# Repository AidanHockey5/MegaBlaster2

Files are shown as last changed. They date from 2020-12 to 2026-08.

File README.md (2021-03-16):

# Mega Blaster 2

Demo video can be found here: https://www.youtube.com/watch?v=4sKwGWfikdc

[Instruction Manual](https://github.com/AidanHockey5/MegaBlaster2/raw/master/man/MegaBlaster2InstructionManual.pdf)

[Store Link](https://www.aidanlawrence.com/product/mega-blaster-2/)

[Discord Link](https://discord.gg/M2skqkZhw2)

This project contains the source material for the Mega Blaster 2, a hardware Sega Genesis/Mega Drive video game music (VGM) player that utilizes the real sound chips. Play any Genesis track on-demand with brilliant sound quality on the actual YM2612/YM3438 and SN76489 PSG synthesizer chips that were found in the real Genesis consoles(1). The Mega Blaster 2 is compatible with both .vgm and .vgz files and can support both the YM2612 and YM3438 simply by changing the DIP switch values. This unit does not use any emulated sound - these are the real chips playing back logged data from the vgm files. 

# VGM Files

VGM files are logged datasets of the data that would have been sent to the real sound chips of whatever console or arcade machine was being sampled. The Mega Blaster 2 simply reads-in this data and sends it to the sound chips at the exact rate specified in the VGM spec, accurately recreating the original sound.

You can find Genesis VGM files here: https://project2612.org/list.php

You can find more VGM files here: https://vgmrips.net/packs/

Please make sure to remove any non-vgm/vgz files before adding them to your Mega Blaster 2's SD card, such as album art images, playlist files, and text files.

# VGM vs. VGZ

VGZ files are gzip compressed versions of VGM files. The Mega Blaster 2 is capable of automatically decompressing these vgz files on-the-fly at a slight performance penalty. If you'd like faster load times for each track, consider decompressing the VGZ files in advance by opening them with a program like [7zip](https://www.7-zip.org/)
The Mega Blaster 2 does not require file extensions in order to operate as it will verify files based on their internal headers.

# Building Your Own Unit

Here are some quick tips for building your own board.

1) You can find an interactive Bill of Materials (BOM) within the `schematic->bom` folder. Open the HTML file in any browser for an easy-to-use part position guide.
2) I use [KiCAD](https://kicad.org/) as my EDA suite.
4) I buy most of my components from [LCSC](https://lcsc.com/). I buy my PCBs from [JLCPCB](https://jlcpcb.com/). If you buy your PCBs from JLCPCB, you can often get a shipping discount on your LCSC parts order.
5) You will need an [Atmel ICE](https://www.microchip.com/DevelopmentTools/ProductDetails/ATATMEL-ICE) or [Jlink](https://www.segger.com/products/debug-probes/j-link/) to flash the bootloader. Once you have flashed the bootloader, all subsequent programming can be done via the on-board USB port. A cheaper option would be to grab a [Jlink EDU Mini](https://shop-us.segger.com/J_Link_EDU_mini_p/8.08.91.htm) as they feature the full functionality of a professional Jlink Unit with the stipulation that it is ONLY to be used for educational purposes. I personally use an Atmel ICE unit. You can find the bootloader bin file in the `bootloader` folder of the repository. [You can find an example of me programming the bootloader using Microchip Studio here.](https://youtu.be/FjPftGuLnGg?t=9259)
6) Once you've flashed the bootloader, you can drag the [.uf2 firmware file found on the releases page](https://github.com/AidanHockey5/MegaBlaster2/releases) on to the "drive" that pops up on your computer, or build from source. If you can't see any "drive," make sure the bootloader mentioned above is flashed correctly, then try double-tapping the RESET button. 
7) If your OS reports a USB fault, you may have a short somewhere on your USB IO lines, power lines, or your 32.768KHz crystal is not hooked up correctly.
8) I use [Visual Studio Code](https://code.visualstudio.com/) with the [PlatformIO](https://platformio.org/install/ide?install=vscode) extension.
9) Make sure your SN76489 PSG chip is orientated correctly. On this board, the PSG is upside-down relative to the rest of the board. The Flash IC is also upside-down. This was done for routing purposes. A small star on the silk-screen indicates the pin-1 position of every IC.
10) For general usage instructions, [please refer to the manual](https://github.com/AidanHockey5/MegaBlaster2/raw/master/man/MegaBlaster2InstructionManual.pdf).

# Reporting Bugs

As you can imagine, this is quite a complex project. There are bound to be bugs to squish, so if you happen to find any, [please report them over on the issues page](https://github.com/AidanHockey5/MegaBlaster2/issues) so I can tkae a look at them! Please try to document the steps it takes to recreate the bug if you happen to know them.

# Schematic

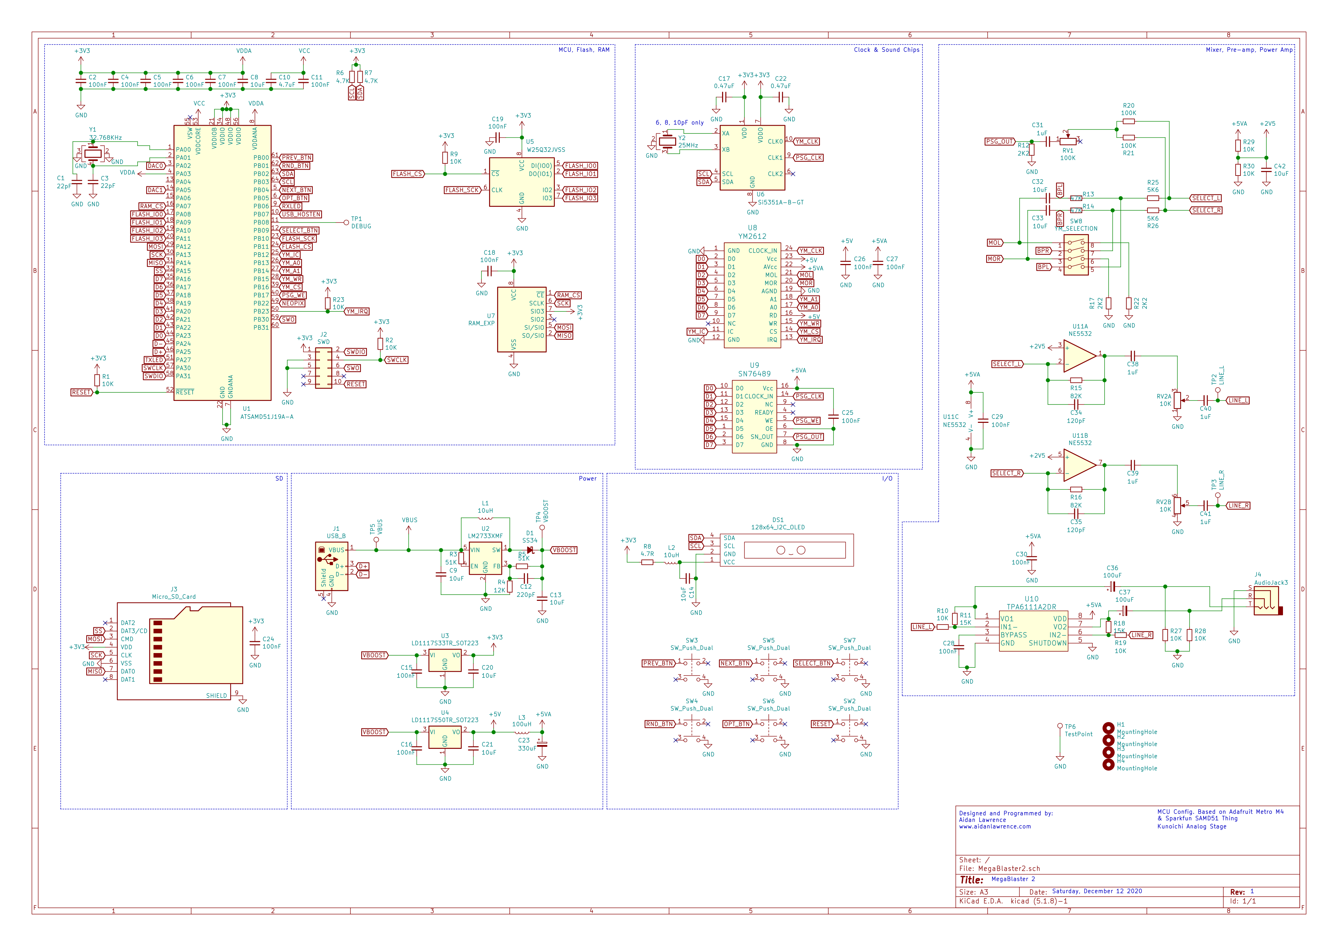
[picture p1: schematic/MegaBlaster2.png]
Schematic


# License
The source code to this project is licensed under the AGPL 3.0 license.

The printed circuit board design files for the Mega Blaster 2, including it’s schematic, gerber files, KiCAD files, bill-of-materials, and 3D models are licensed under the Creative Commons Attribution-NonCommercial-ShareAlike 4.0 license.

You are permitted to build your own Mega Blaster 2 units for personal use. You are not permitted to sell said units.

(1) Pedantic note: Discrete YM2612 ICs were indeed included on some models of the Genesis, but the SN76489 PSG and YM3438 were found baked into ASIC chips on the actual consoles. The PSG's noise is slightly different on the ASIC version.

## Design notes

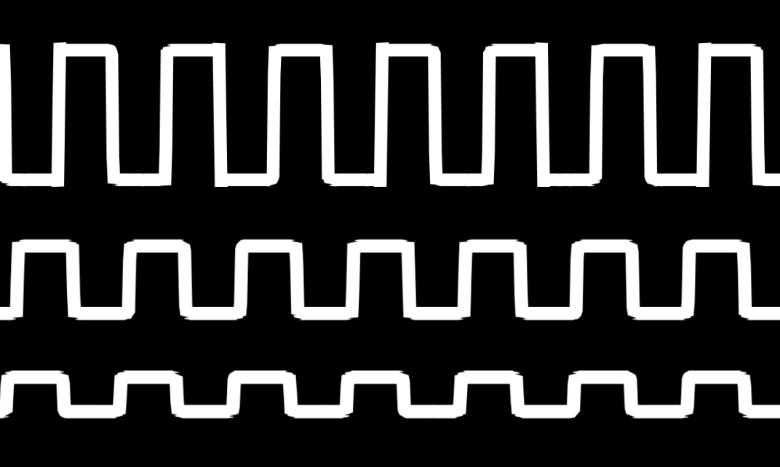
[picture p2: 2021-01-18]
schematic/Art/Square_half.bmp

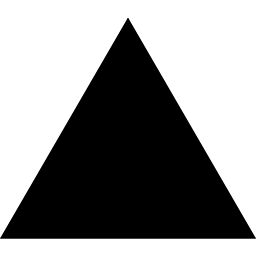
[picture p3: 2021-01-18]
schematic/Art/Triangle.bmp

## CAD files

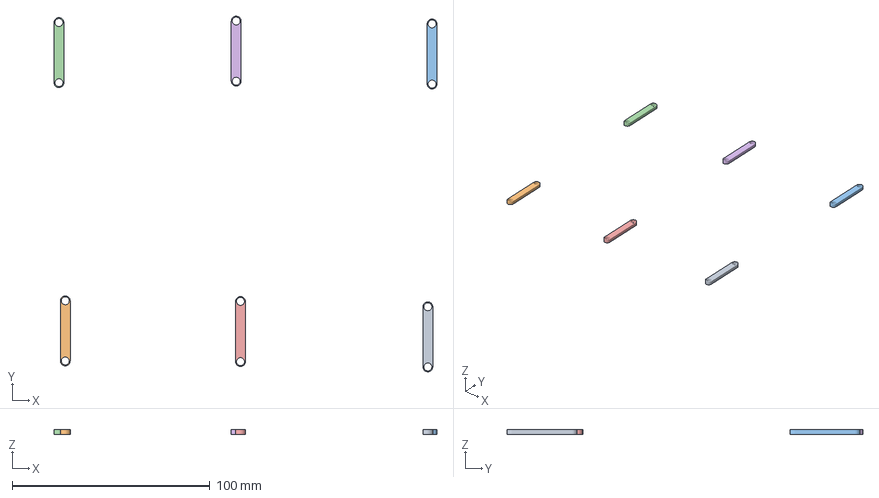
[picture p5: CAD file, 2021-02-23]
3D_Print/6x_OLED_Spacer_1.3mf
193.7 x 179.9 x 2.50 mm
OLED_Spacer_1.stl x 6

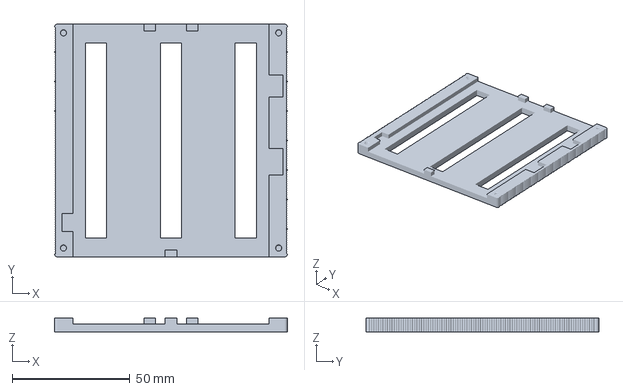
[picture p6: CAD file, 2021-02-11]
3D_Print/MegaBlaster2_Baseplate_V3.3mf
99.0 x 99.0 x 6.00 mm

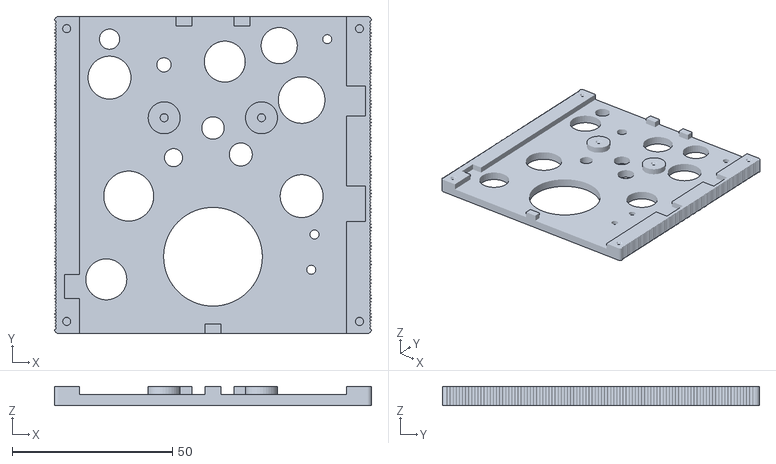
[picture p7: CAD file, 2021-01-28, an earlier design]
3D_Print/MegaBlaster2_Baseplate_V1.stl
99.0 x 99.0 x 6.00

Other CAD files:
3D_Print/MegaBlaster2_Baseplate_V2.3mf
3D_Print/MegaBlaster2_Baseplate_V2.stl
3D_Print/MegaBlaster2_Baseplate_V3.stl

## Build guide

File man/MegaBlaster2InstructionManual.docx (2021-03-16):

MEGA

BLASTER

2

Sega Genesis / Mega Drive Video Game Music Player

User Manual

Aidan Lawrence

www.aidanlawrence.com

March 2021

# Quick Start

The Mega Blaster 2 is designed to play both uncompressed (.vgm) and compressed (.vgz) Video Game Music (VGM) files. The device will read-in VGM files from the SD card, parse them, and send the data inside of those files to the sound chips, accurately recreating the music using authentic hardware.

In order to use the Mega Blaster 2, you must have:

- A microSD card formatted to FAT32 (plus an SD card reader for your PC).
- A standard USB-B cable and a USB port (for power. Standard USB phone chargers also work).
- 3.5mm audio cable for external speakers/line devices OR headphones with a 3.5mm jack.
- (Optional USB support) Windows 7 and 8 users will need a driver, which you can download here. (https://github.com/adafruit/Adafruit_Windows_Drivers/releases/download/2.3.4/adafruit_drivers_2.3.4.0.exe)

Format the SD card to FAT32. Load the SD card with VGM files on your PC. Be sure to remove any non-VGM files (album art images, txt files, m3u files, etc. should not be placed on the SD card). Eject the card and insert it into the Mega Blaster 2. Plug-in the Mega Blaster 2 via USB to power-on. After the power-on-self-test and boot screen, your device should be ready to go!

If you have any questions about the operation of the Mega Blaster 2, feel free to send me an email. You can reach me via my Contact page on my website:

https://www.aidanlawrence.com/contact/

or visit the Discord server: https://discord.gg/5rDChhUexQ

# Device Guide

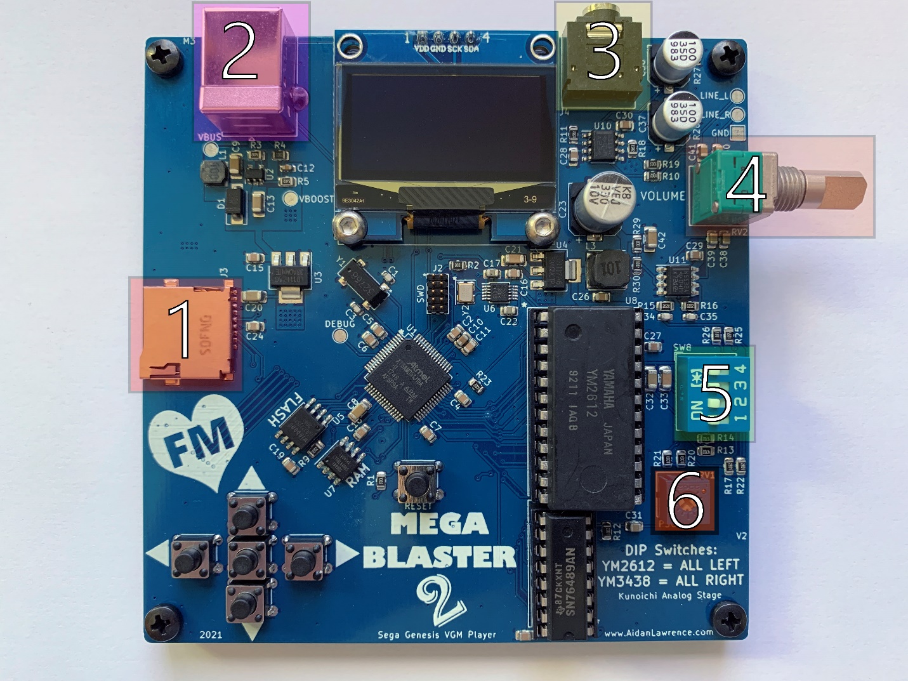
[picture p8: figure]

1) Micro SD Card Socket: Push your SD card in until you hear a click. Push the card again to eject.
2) USB Connector: Power your device using a USB-B cable. Any USB port should be able to supply enough power to the Mega Blaster 2, including PC USB ports and 5V cellphone chargers.
3) Audio Out Jack: TRS amplified audio out. The Mega Blaster 2 features a small headphone amplifier, so directly driving phones is OK. Line level outputs are broken out on the upper right-side of the board, though, it’s probably much easier to simply lower the volume for driving line-level input devices if clipping is occurring.
4) Volume Knob: A simple volume potentiometer. Clockwise turns increase the volume, counterclockwise turns decrease the volume.
5) YM2612/YM3438 Selection DIP Switches: YM2612’s and YM3438’s have different output impedances. Use these DIP switches to select the correct mixing resistors.
  a. For YM2612: Set all DIP switches to the LEFT side.
  b. For YM3438: Set all DIP switches to the RIGHT side.
6) PSG (SN76489) Mix Volume: This potentiometer adjusts the PSG square wave volume. You can use a screwdriver to turn this potentiometer. Clockwise for a quieter PSG, counterclockwise for a louder PSG.

# SD Card Setup

You must format your SD card as a FAT32 device. You can simply use your built-in operating system’s tools to format your card or use the official formatting tool from the SD Association. (https://www.sdcard.org/downloads/formatter/)

Folders/directories are supported on the Mega Blaster 2. However, due to memory restrictions, the device will only read one level deep into a directory structure. Basically, that means you can have folders, but you cannot have folders-within-folders. Files placed on the root directory of the SD card are also OK.

Please only include .vgm and .vgz files for best performance (.vgz files may take slightly longer to start playing due to decompression). Make sure to delete any non-VGM files.

If your SD card fails to read, the display will warn you on start-up.

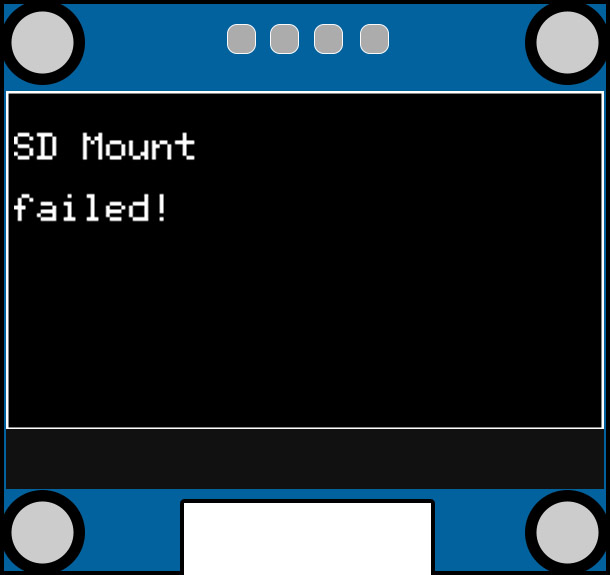
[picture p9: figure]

Check that your card is formatted to FAT32 and is not physically damaged. If you happened to have interrupted the card via a reset, programming cycle, or the player has crashed; remove the card, reinsert the card, and then press the RESET button.

On Windows, drives larger than 32GB will lose their option to be formatted as FAT32 devices in the default Windows formatting tool. You can use a tool like FAT32 Format GUI (http://ridgecrop.co.uk/index.htm?guiformat.htm) to get around this limitation.

# Chip Verification

The Mega Blaster 2 will automatically verify your YM2612/YM3438 chip on every startup by setting the internal timers and listening for specific interrupt intervals from the IRQ pin. If the Mega Blaster does not detect these specific pulses from the IRQ pin within one second after startup, the player will lock up and flash a warning on the screen prompting you to power the device down and remove the offending sound chip. This procedure is to combat the growing number of fraudulent chips being passed as YM2612/YM3438’s and to warn the user before any possible damage occurs from using a counterfeit chip.

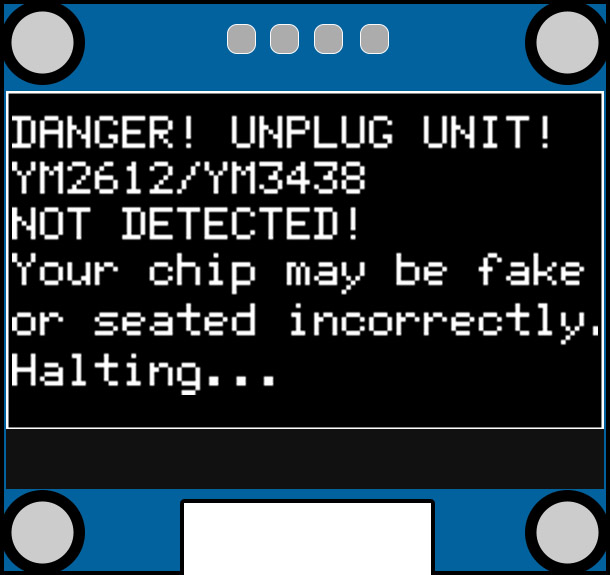
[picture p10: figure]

If you see the above message after you power up your device, immediately remove power and remove the YM2612/YM3438. Your chip has likely been detected as a fake. You may also see this message if your chip isn’t seated correctly or there is a hardware fault such as a short circuit or a damaged component.

Regardless of the issue, if you see this screen, then something isn’t right!

# Video Game Music (VGM) Files

Video Game Music files, referred to as “VGM files,” are essentially log files of the data that was sent to the sound hardware on the real versions of their target consoles/arcade machines. The Mega Blaster will interpret these data logs and send commands to the sound chips at nearly the same time as the real hardware would have sent data over to its sound chips. The result is a near 1:1 recreation¹ of the original sound on-demand that’s fed through modern amplification circuitry to produce a crystal-clear output. There is absolutely no emulation here – everything is being synthesized on-the-fly using the genuine sound chips.

You can download Genesis/Mega Drive VGM files here: https://project2612.org/list.php

The Mega Blaster 2 also supports any VGM file that leverages the SN76489 PSG, such as Sega Master System VGMs.

Additional VGMs can be found here: https://vgmrips.net/packs/

Please note that Sega CD and 32X VGMs are not supported as they used separate sound hardware. 3rd party tracks that utilize DAC streams are supported, however. VGMs that use chips other than the YM2612/YM3438 and SN76489 PSG are not supported.

# VGZ vs VGM

VGZ files are compressed VGM files. The Mega Blaster 2 supports both compressed and uncompressed VGM files natively. However, it’s a better idea to use decompressed VGM files on your Mega Blaster 2 as it will drastically increase your performance as no decompress cycle needs to happen before each track.

You can use a tool like 7zip (https://www.7-zip.org/download.html) to easily extract the VGM files out of VGZ files.

File extensions, or lack thereof, do not matter.

¹Time resolution on microcontroller timers isn’t infinite, so there will be an ever-so-slight variation in timing compared to the real hardware (~0.1% inaccuracy). This really isn’t perceptible to humans though, so it’s pretty much a non-issue, but is worth mentioning for the sake of disclosure.

# The Main Menu

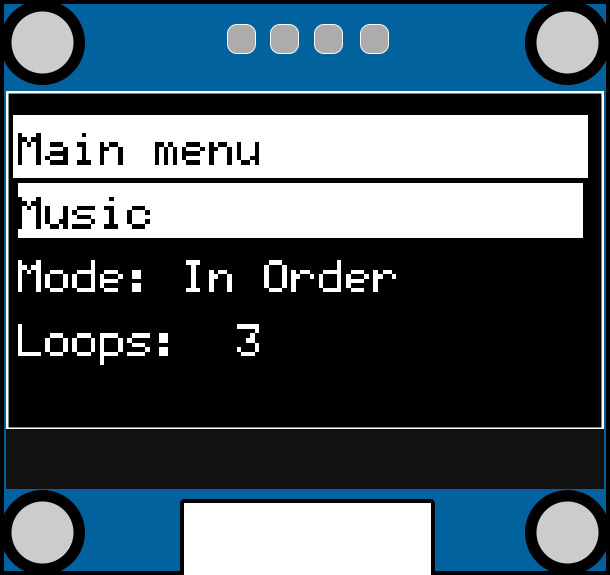
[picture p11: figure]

Once your Mega Blaster 2 boots, you will be placed onto the main menu screen. Here, you can access your music browser and change settings.

You can use the directional buttons on the bottom left of the Mega Blaster 2 to move around this menu. The middle “select” button (and the right arrow button) can be used to enter menus and options.

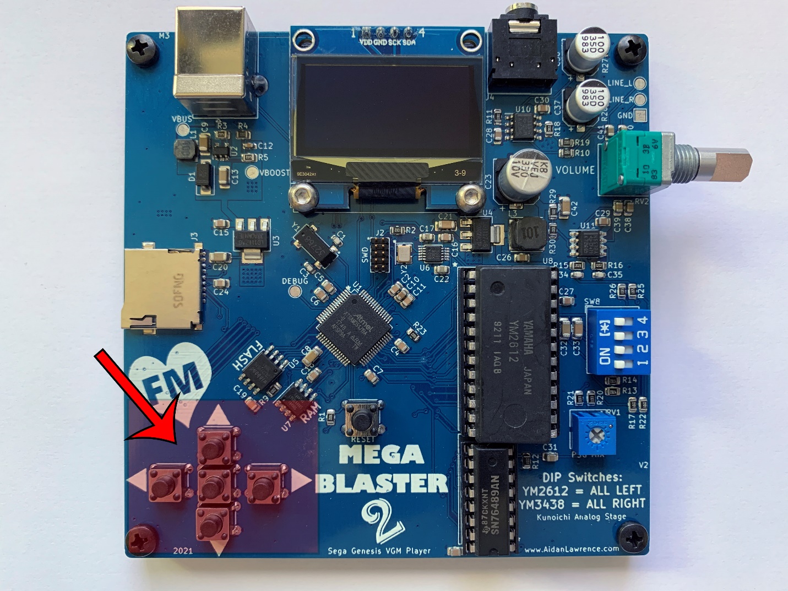
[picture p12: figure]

# File Browser (Music Menu)

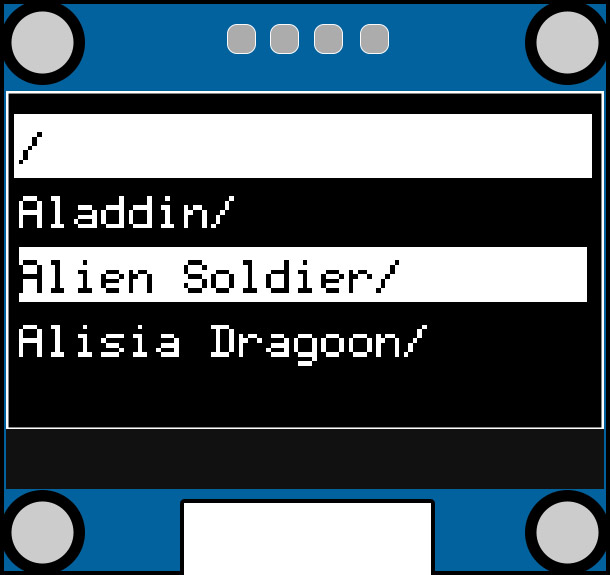
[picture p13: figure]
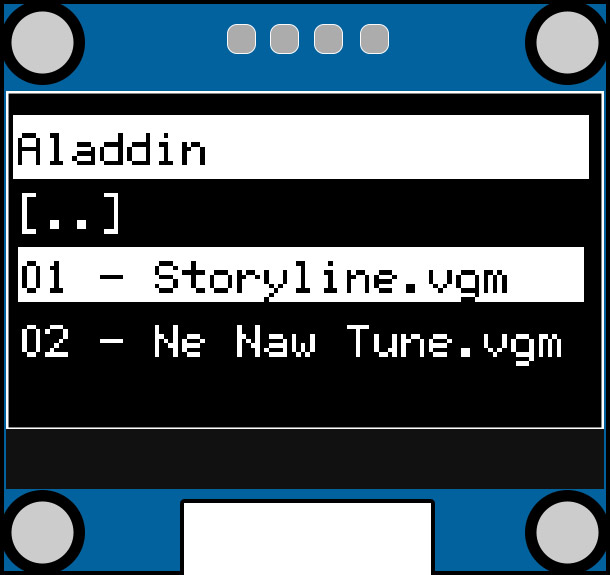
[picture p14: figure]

To access your video game music tracks, you will need to interface with the file browser found under the “Music” main menu option.

Simply use the up and down keys to scroll through your folders and files. You can enter directories and select files using the middle select button or the right arrow button. You can leave a directory by using the left arrow button, or by selecting the [..] entry.

Once a valid VGM or VGZ file is selected, the player will automatically verify it and begin playing. You will be taken to the Track Information screen.

Note: the _SYS directory is created by the Mega Blaster 2 itself and should simply be ignored. This directory is where the decompressed VGM data is stored.

Files are read in-order directly from the SD card. They are not sorted in alphabetical order. If you’d like your SD card to be sorted in alphabetical order, you will need a tool that sorts your files in advance.

SD Sorter (https://www.trustfm.net/software/utilities/SDSorter.php) does this admirably.

# Track Information Screen

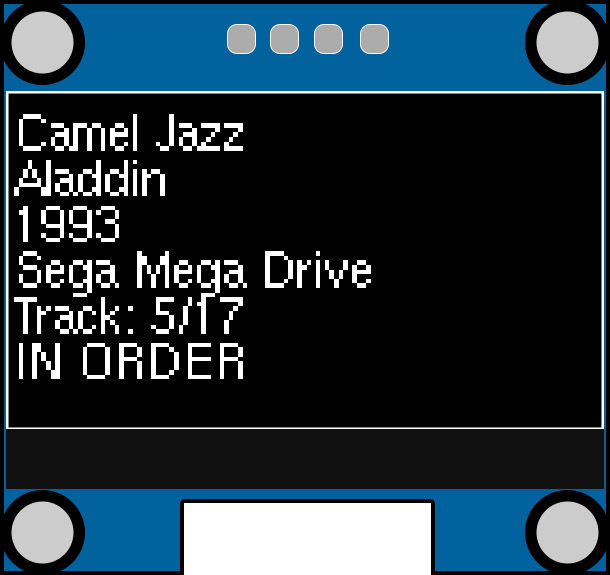
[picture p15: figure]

While the device is playing a track, the information screen will appear. Here, you will see the following information:

Track name

Game Name

Date of Game Release

Game System

Track #/# of total tracks in directory

Play Mode (IN ORDER/LOOP/SHUFFLE DIR/SHUFFLE ALL)

You can exit this screen at any time and return to the menu system by pressing the middle select button.

If you idle in the menu system, the Mega Blaster 2 will automatically return to this screen.

If you are in the “Shuffle Dir” or “Shuffle All” play mode, the current track number is not shown.

# Info Screen Controls

While in the information screen, your controls will automatically change to playback controls.

The up and down keys are disabled.

The middle select button will return you to the menu system.

The left and right buttons will move you forwards or backwards through the tracks depending on your current play mode.

If you are set to the “In Order” or “Loop” play mode, your left and right buttons will cycle through the files in your current directory in order.

If you are set to the “Shuffle All” or “Shuffle Dir” play mode, your left and right buttons can be used to travel in-order through the random shuffle history. Once you’ve reached the near-end of the random shuffle history using the left arrow button, you won’t be allowed to go back any further. Once you’ve reached the far-end of the shuffle history using the right arrow button, a new track will be randomly selected and stored in the shuffle history in case you’d like to go back to it at any point.

# Play Modes

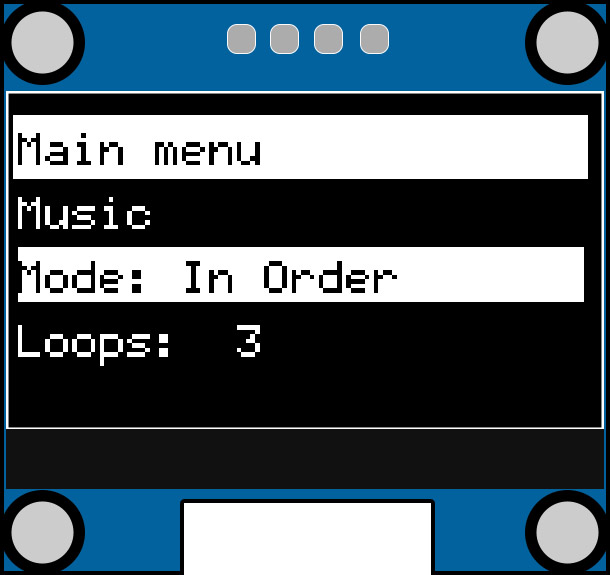
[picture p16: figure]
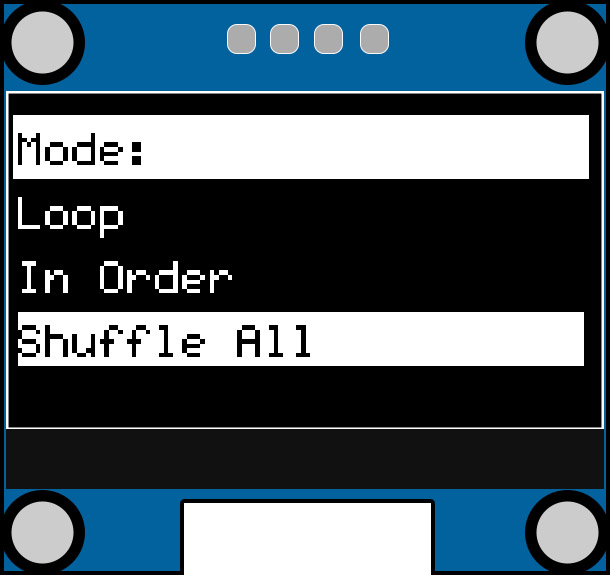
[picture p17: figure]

The Play Mode menu allows you to select the player’s automatic track swapping behavior.

There are 4 possible play modes to choose from:

Loop: Re-play the current track perpetually until manually changed by the user.

In Order: Once a track is chosen, the player will automatically proceed to the next track file in the current directory after the previous track ends.

Shuffle All: This option will automatically start playing the entire SD card in a random order. Every single VGM track on-board is eligible to be selected at random after each track ends.

Shuffle Dir: Similar to the “Shuffle All” function, but the pool of tracks to pick from is confined to a single directory.

The default value is “In Order.”

# Adjust Number of Loops

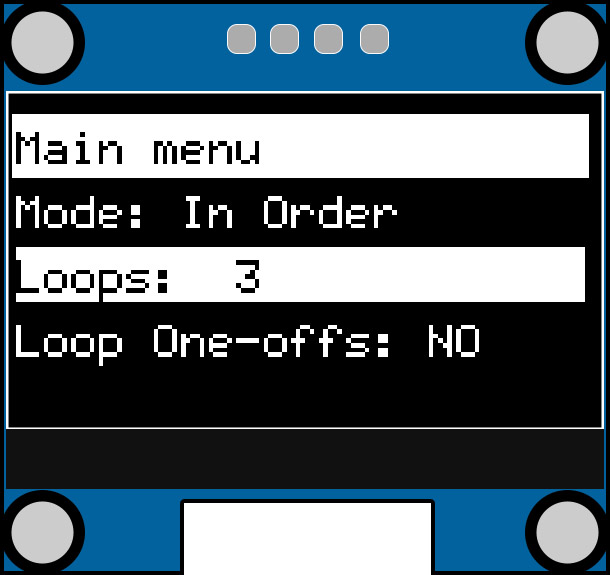
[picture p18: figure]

The “Loops” option will allow you to change the number of times a track will loop before ending. To change the loops value, highlight it with your cursor and hit the middle select button.

For fine control, hit the select button once. A colon character ( : ) will appear next to the value. Use the up and down buttons to adjust the loops by 1.

For coarse control, hit the select button once again. An angle bracket character ( > ) will appear next to the value. Use the up and down buttons to adjust the loops by 10.

Finally, hit the selection button once more to exit.

The default value is “3.”

Note: If your play mode is set to “Loop,” this value will be set to 65535 (Internally, the Mega Blaster 2 reads this as 0xFFFF, indicating that a track should be looped forever).

# Loop One-offs

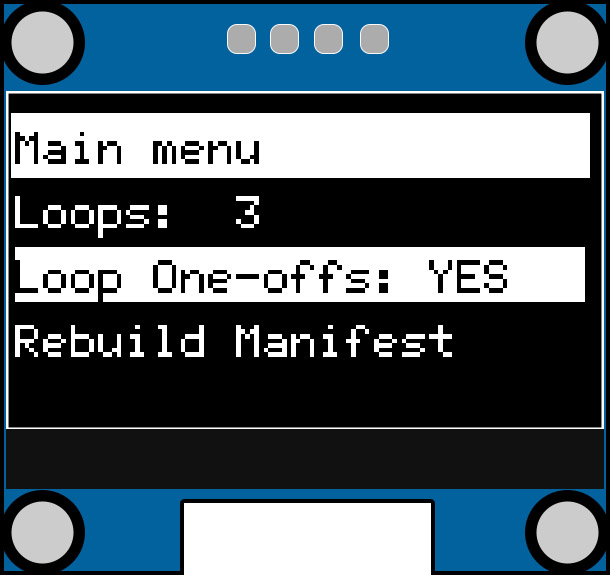
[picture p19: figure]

This option will give you the ability to change if one-off tracks will loop just like any other track. Usually, one-off tracks are things like game-over themes, intro themes, or other minor jingles.

You can adjust this setting by highlighting the option, hitting the middle select button, then using the up and down buttons to change the value. Once you’ve selected your value, hit the middle select button again to set.

This option defaults to “NO.”

# Audio Performance Considerations

The Mega Blaster 2 uses custom power filtering circuitry and careful PCB routing to ensure the best possible signal-to-noise ratio. Any device with a USB port should be able to power the Mega Blaster 2 just fine, but there are still a few considerations to make depending on your configuration.

# Ground Loops

If you power your Mega Blaster 2 via your computer’s USB port and connect the audio output to the same computer’s line-in, you will form a ground loop and will likely hear a loud buzzing noise or amplified electromagnetic interference. You can easily solve this issue with a cheap ground loop isolator. They look like this:

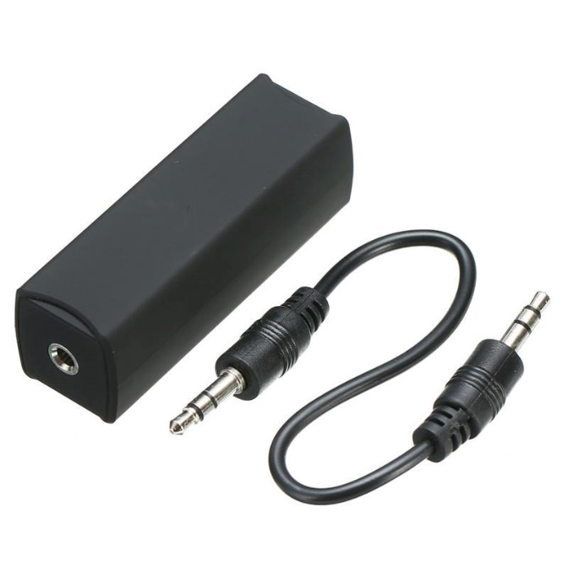
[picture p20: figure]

Keep in mind that many ground loop isolators are designed with a low-pass filter built-in and this can affect audio quality. Users with headphones directly connected to the Mega Blaster 2 will not have to worry about such ground loops.

Alternatively, you can use an external power source like a 5V portable battery bank to power the Mega Blaster 2. This will eliminate the need for a ground loop isolator.

On the topic of headphones: The Mega Blaster 2 does feature a small headphone amplifier on its output. The onboard headphone amplifier is the TPA6111A2 and is capable of delivering up to 150mW of power directly to headphones. The TPA6111A2 is a linear class AB amplifier. You can read more about its specifications in the TI datasheet. (https://www.ti.com/lit/ds/symlink/tpa6111a2.pdf?ts=1612621494673)

Finally, it’s important to distinguish the noise floor differences between the YM2612 and the YM3438. The YM2612 has a higher noise floor than the YM3438. YM2612 users may be able to hear a very slight white-noise hiss when the unit is not playing any music. This is totally normal and is an artifact of the time-division multiplexor cycling through each of the FM channels. There is no way around this noise floor as it is literally the YM2612 itself producing it. It’s one of the quirks of using real hardware instead of an emulator! The YM3438 has a noticeably lower noise floor.

# Firmware Updates

The Mega Blaster 2 features an easy-to-use UF2 bootloader which makes updating the onboard firmware as easy as dragging a file to a flash drive.

## Windows, MacOS, and Linux

If you’re using a Windows 10, MacOS, or Linux computer, your driver should install automatically. Otherwise, Windows 7 and 8 users should install the Adafruit drivers found here. (https://github.com/adafruit/Adafruit_Windows_Drivers/releases/download/2.3.4/adafruit_drivers_2.3.4.0.exe)

Updating your firmware is as simple:

1) Download the latest .uf2 firmware file from the GitHub Repository Releases (https://github.com/AidanHockey5/MegaBlaster2/releases/) page.
2) Double-tap the RESET button on your Mega Blaster 2. A new “drive” named “MB2BOOT” should pop up and/or be available in your “This Computer” or drive browser.
3) Drag the UF2 firmware file on to this “drive” just like a flash drive. Once the Mega Blaster 2 verifies the file, it will automatically flash itself and reboot.
4) You may need to remove and reinsert your SD card, then hit the RESET button a single time.

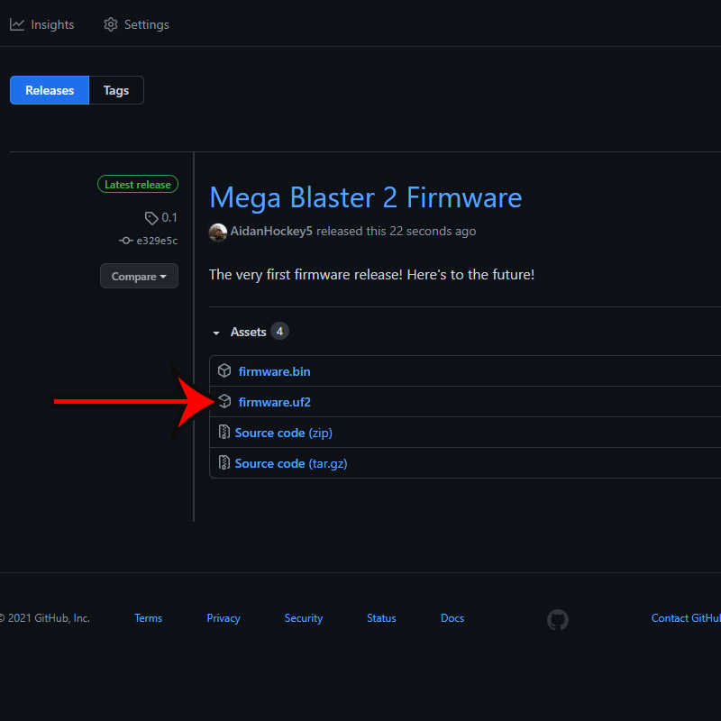
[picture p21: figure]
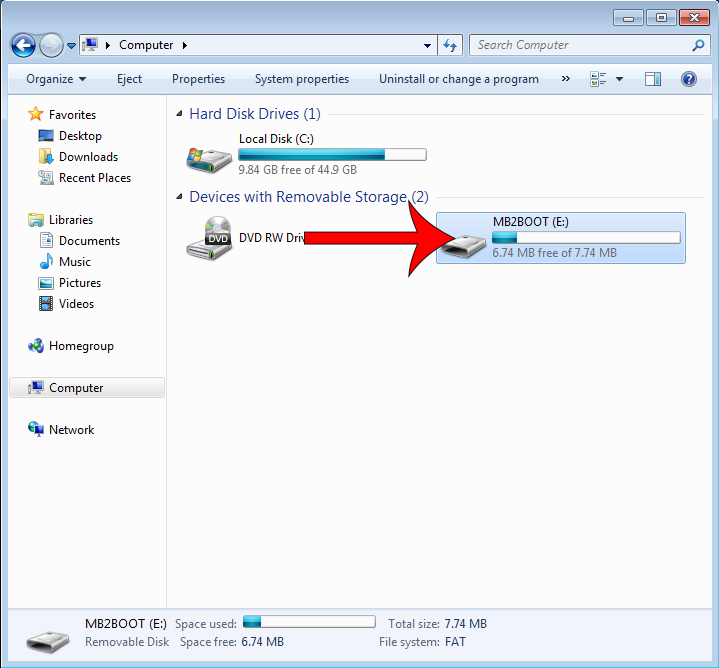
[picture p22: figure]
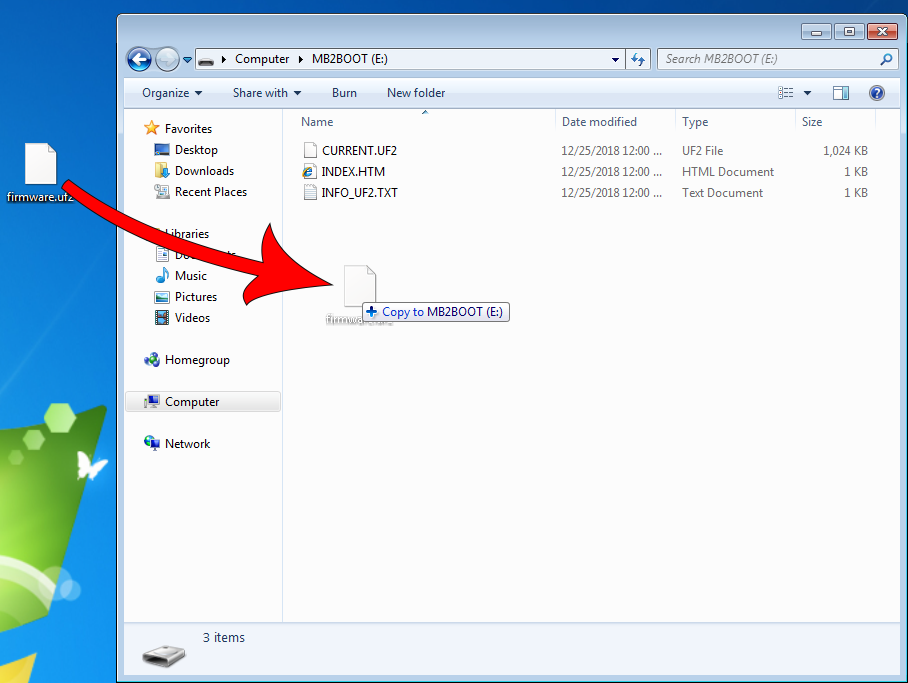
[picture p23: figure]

The process is the same for MacOS and Linux (lubuntu shown here).

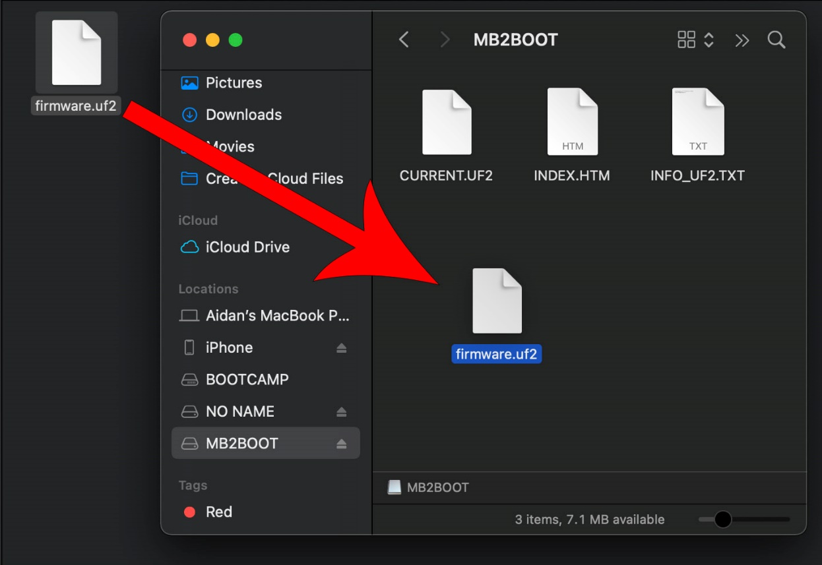
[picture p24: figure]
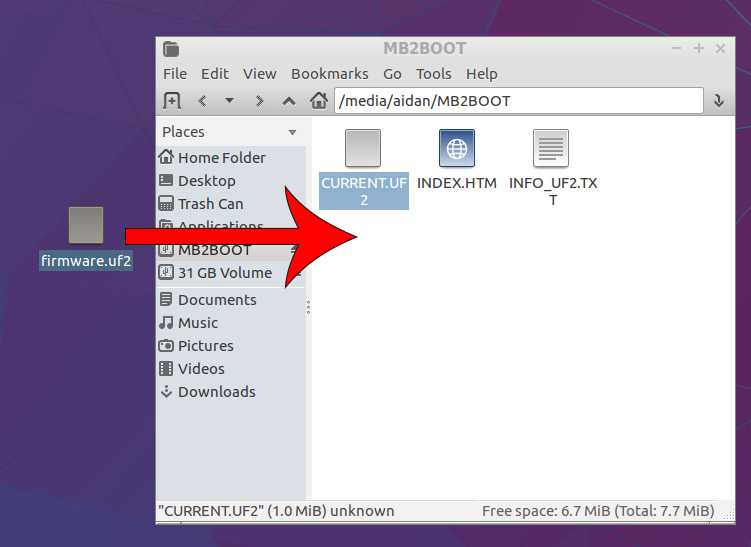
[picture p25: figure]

# Getting Help

Stuck updating? Have any questions or comments? Just want to chat about sound chips?

Feel free to join the Discord server! https://discord.gg/5rDChhUexQ

…or contact me via email here: https://www.aidanlawrence.com/contact

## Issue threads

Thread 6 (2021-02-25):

Directories that begin with the same string are indexed incorrectly

AidanHockey5, 2021-02-25:
A new issue has been found where if two directories begin with the same string, the player indexes them incorrectly.

For example, if you had two directories from the same franchise, they might have folders like this:

```
Shining Force
Shining Force II
```

The player will then index both of these folders together, giving incorrect values on how many tracks are actually in a specific folder. Eventually the player will jump out of those bounds and end up in an invalid state.

The probable cause of this issue is due to how the Arduino Menu library indexes directories using a `startsWith()` function, or something along those lines. Fixing this issue might take a little while due to the inherent complexity of the library, but I am aware of it.

A work-around right now would be to start similar directories with numbers preceding them, like so:

```
1_Shining_Force
2_Shining_Force
```

birdybro, 2021-02-28:
Also probably related to the same thing...

[MANIFEST.txt](https://github.com/AidanHockey5/MegaBlaster2/files/6058037/MANIFEST.txt) <--- my manifest.

Added some to the manifest to test, it got reallly crazy from here. Everything in a strange order now, looks the same upon forcing a manifest rebuild. Also randomly now a bunch of tracks just skip around.

Just noticed the freefilesync db file, removing that file to see if it clears up the issue. At first I was thinking that some arcade system tracks with compatible chips were just not playing for whatever reason. Saw a strange one where columns 2 arcade was just rapidly changing tracks and I couldn't stop it, had to pull the plug. Interesting.

Deleting the ffs sync db file didn't fix the issue. Upon initial boot columns 2 does the same loop through tracks infinitely. If I play some other stuff, then it works occasionally. Kinda strange.

AidanHockey5, 2021-02-28:
Hrm.. interesting. A friend of mine reported an issue with their manifest file too similar to yours. The text portion of the manifest file looks like it generated successfully, but the metadata bytes concatenated to the end look duplicated.
Try deleting the _SYS folder on your machine and letting the player generate a brand new manifest from scratch.

I'm actually going to be out of office for the next week, so I'll be on bug patrol the following week. Ditching this manifest system is something that I'd like to do in the future, but that's a pretty big fix, so it might take a bit of time. Hopefully the new system will patch out the original issue above too.

birdybro, 2021-03-08:
Just as an update for the purposes of providing more data if you need it, when I redid the manifest entirely, this is the result:

[MANIFEST.zip](https://github.com/AidanHockey5/MegaBlaster2/files/6104599/MANIFEST.zip)

Still gets out of order by the end of it.

When I wipe the manifest and start over, same result. So at least it's reproducible! :)

AidanHockey5, 2021-03-09:
Yeah, I’m on my way back from a trip and am thinking of a way to remove the
manifest system entirely. I’m not entirely sure what your unit is doing. I
wonder if a track file name happens to have a weird character in it or
something is overflowing.

I’ll certainly take a look at this when I get home and see what I can do.

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

AidanHockey5, 2021-03-12:
Just a progress report on this issue:
I've been working on a new way to ditch the manifest system at the expense of a little more memory usage. I've got a version that seems to be working pretty well right now as of [this commit](https://github.com/AidanHockey5/MegaBlaster2/commit/1779ea2c6d107876efd6414b146e4b1de1a98458)

Much more testing will be required before it's all done, but early signs look good. I'd also like to create a system to delete or avoid garbage OS files and directories like .DS_Store etc. Those files tend to not do anything terribly important and really only seem to exist to gum up my projects lol.

birdybro, 2021-03-12:
I am curious as an amateur at all this... Given that the chip you used in your design has instruction and data cache on the chip (unlike a typical arduino chip), have you explored the possibility of converting portions of your code from conditional programming (if-else, etc...) over to "branchless" (buzzword) programming (for then an array, then only do things on that which is in the array).

I've read it can reduce the load on instructions and cache in general to improve efficiency, but I can guess why this would be hard with something like VGM which has a lot of unpredictable variables I'm sure.

AidanHockey5, 2021-03-12:
Generally speaking, the compiler will handle optimizations like that.

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

AidanHockey5, 2021-03-12:
The manifest system as been removed as of this commit, though, that was a separate issue.

The current issue with the sequentially named folders has been determined to be a problem with the SdFat library that I'm using, not the menu library that derives from it. I've created another issue on the SdFat page[ here.](https://github.com/greiman/SdFat/issues/273) Hopefully we can get a resolution from that post as the SdFat library is very, very complicated.

birdybro, 2021-03-13:
Thanks for your work on this! :)

AidanHockey5, 2021-03-13:
[Fixed as of this commit!](https://github.com/AidanHockey5/MegaBlaster2/commit/7147d6a32b26ee4d21832b701189e093dd09d2b5)

[You can download the new firmware here](https://github.com/AidanHockey5/MegaBlaster2/releases/tag/1.2)

Thanks to @greiman for the help!

Closed 2021-03-13.

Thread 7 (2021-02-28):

MDFourier results point to many improvement opportunities.

birdybro, 2021-02-28:
Just want to start by saying I love the project and have been having a blast with it. Finally got in my SN76489AN chips (authentic pulls from Twisty Wrist Arcade). Thanks Aidan! This feedback is just to help the project, definitely not a complaint. Part of the reason I bought the board was because I wanted to get the MDFourier results. Hopefully these results help you with future firmware updates.

## Summary

* Noise channel has very large differences, very obvious upon listening to the MDFourier tone generator when it gets to the noise section. This might be unavoidable since the DCSG is different fundamentally than the one used in the real Sega Genesis (which was integrated into the VDP and modified very slightly).
* Pitch is overall different.
* 100Hz to 10kHz+ frequencies are more pronounced indicating a high pass filter (or potentially phase inversion?). This is less of an issue overall, since you probably weren't looking to simulate some specific Sega Genesis model's audio filtering. Also, it's more "transparently" representing these chips in a way, so it's kind of a good thing as a focus.

### Graphs

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
All differences. Note bottom right pointing out pitch differences. When using -R command to adjust the sample rate to match though...

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
You can see that this throws off the comparison more, because now we are probably getting closer to per-sample frequency comparisons.

When compared to a MD1-VA6 without rate adjustment:
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
Things are much tighter but still a heavy high-pass filtering effect. Obviously this.

Then when compared to another original hardware sample to be thorough. This test is my recording off of my MD1-VA3's Headphone jack using the latest build of Deadfish's VGM Player ROM builder (https://mega.nz/file/BRYixB4Q#-yRrWiNo7WYILCeB2ZBq4gCpd8A_xi-So2zIj2lYvUE) which can disable the VDP to dramatically reduce noise floor (video is always unplugged physically for our tests, but the VDP still produces a lot of noise), compared against the MegaBlaster 2 sample. This is to further reduce the possible differences that can be accounted for in the frequency plot due to excess noise.
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
As you can see there is still a very heavy high-pass filter effect going on (or phase inversion?) on FM and SPSG. The pitch is still off by the same amount (1.82%).

Feel free to contact me if you'd like me to test nightly releases that you don't feel comfortable posting here or something like that.

kevinscoleman@protonmail.com

### Tools Used

MegaBlaster 2 running v1.00 firmware release.

Motu M4 USB Audio Interface Line 1-2 input, balanced gain manually to 9'o clock position roughly.

https://www.retrodev.com/blastem/nightlies/blastem-win64-0.6.3-pre-1e7a63f0ccf4.zip - This is the version of BlastEm! used to log the VGM for the latest MDFourier test.

http://junkerhq.net/MDFourier/ - MDFourier for reference.

### Files

[MDFourier-1.21.vgm.zip](https://github.com/AidanHockey5/MegaBlaster2/files/6057205/MDFourier-1.21.vgm.zip) - This is the VGM used for the test.

[A-MD1UTVA3-M192-96khz-24b-2021.zip](https://github.com/AidanHockey5/MegaBlaster2/files/6057219/A-MD1UTVA3-M192-96khz-24b-2021.zip) - This is the reference used, latest good 96kHz recording from Artemio Urbina.

[MegaBlaster2_v1.00_96khz.flac.zip](https://github.com/AidanHockey5/MegaBlaster2/files/6057227/MegaBlaster2_v1.00_96khz.flac.zip) - This is the sample I took on my Motu M4 Interface at 96kHz/24-bit as I commonly do.

[A-MD1UTVA3-M192-96khzxfl_vs_MegaBlaster2_v1.00_96khz.zip](https://github.com/AidanHockey5/MegaBlaster2/files/6057234/A-MD1UTVA3-M192-96khzxfl_vs_MegaBlaster2_v1.00_96khz.zip) -  Here are the results from MDFourier zipped up.

AidanHockey5, 2021-02-28:
Hello!

Thank you for taking the time to do these sorts of measurements. I'll go ahead and address the discrepancies the best I can.

1) Noise differences on the PSG: Yeah, this one is unavoidable. The discrete PSG simply has a different noise pattern than the one built into the VDP. No getting around that. [This resource has visualizations of the noise differences.](https://www.smspower.org/Development/SN76489?from=Development.PSG#NoiseChannel)

2) Could you define what you mean by pitch? The pitch of the YM2612 is directly dictated by the Si5351 clock-gen IC that is referenced to a 25MHz crystal. My measurements always landed me within a 1% margin of error for the clock. The Si5351's are extremely accurate clock synths, so I'd be comfortable ruling them out as the cause of this issue. Basically, the clock for the YM2612 is so close that you'd need a machine to notice any difference in pitch - it's imperceptible by humans.
Timing, however, is likely more of an issue, though again, the accuracy differences are so minute that it's very unlikely to be noticeable on human time scales.
My VGM driver is "time-lossy" in the sense that if the MCU is ever falling behind because it was blocked processing something else, or a VGM command is taking a while, it will rush through as many samples as it can to "catch up." This is most noticeable if you scroll through a menu while a VGM is playing. You can hear pronounced jumps in time as the driver catches up after being blocked by a screen draw. I'm limited on absolute time resolution since there's only so much resolution in an MCU's timer. A lot of time is spent just waiting for the chips to process their writes, so having 1:1 accuracy to an actual console is probably not possible with my driver. Again though, the time differences are so minute that it's simply not noticeable on human time scales, so I'm not too worried about it. There is around 60ms per minute of worth of time inaccuracy (0.1%), which is extremely tiny, but noticeable on machine time scales. It's just one of the quirks of dealing with the VGM format on embedded devices.

3) The filtering differences don't really surprise me. The filters are indeed different and this was an intentional design decision. This is totally my own opinion, but I think the actual consoles have a really lackluster analog stage and sound pretty bad. The original Mega Blaster design tracked Sega's schematic pretty closely, at least for the mixing and preamp portion, and had pretty "meh" results, but this new design is based on the Kunoichi analog stage originally designed by @natarii
I'll ping her and see if we can get some information from her perspective. Personally, I absolutely love the sound profile this analog stage design brings, so I don't think I'll be changing anything there.

Hopefully that gives you some insight on to these differences!

birdybro, 2021-02-28:
1. Okey doke! I figured that was going to be the case. The VDP-based DCSG implementation is different after-all, has a different pitch. I heard this can be accounted for though. What you are saying basically mirrors @ValleyBell's comments to me in a discord channel when I inquired about it. The firmware can account for it somewhat, but then there may be other problems like noise artifacts as a result. Thanks for the insight!
2. Yeah, if this is just a limitation of the hardware, obviously not a big deal. Just was curious to do this testing to see where it landed :) on the timing side of things. The best way to show you what I mean is probably from the verbose log in MDFourier when comparing the two (note this is 96kHz, not 44.1kHz, so adjust math accordingly, but the percentage difference will just be more detailed as a result):
```
* Loading 'Reference' audio file C:\MDFourier-Genesis-SegaCD-Recordings-14062020\Recordings-2020-06-14\A-MD1UTVA3-M192-96khz-24b-2021.flac
 - Decoding FLAC
 - Audio file is 96000Hz 24bits PCM Stereo and 61.41 seconds long
 - Sync pulse train:
	   1.19694s [114906 samples]
	 to 59.6065s [5722227 samples]
 - Detected 59.9217 Hz video signal (16.6885ms per frame) from Audio file

* Loading 'Comparison' audio file C:\MDFourier-Genesis-SegaCD-Recordings-14062020\MegaBlaster2_v1.00_ym2612_02-28-2021\MegaBlaster2_v1.00_96khz.flac
 - Decoding FLAC
 - Audio file is 96000Hz 24bits PCM Stereo and 60.0005 seconds long
 - Sync pulse train:
	   0.367031s [35235 samples]
	 to 58.8364s [5648299 samples]
 - WARNING: Comparison file framerate difference is 0.0175476 ms per frame.
 - Estimated sample rate is off: 96100.945076hz calculated from signal length
  The source might have a timing difference.
 - Expected 58408ms and got 58469.4ms (Difference is -61.4167ms/-3.68029 frames of 16.688ms/-5896 samples)
 - Pitch difference in cents: 1.81946
 - Detected 59.8604 Hz video signal (16.7055ms per frame) from Audio file

= Different frame rates found (0.0170923), compensating to 16.6885 =
```
So this just means it took this much longer --> (5896/96,000ths of a second) - to finish the tone generator VGM than original hardware does. Artemio just corrected me in chat, it's cents not percent X_X sorry about that. So the difference is 100.10515112083333333333333333333% that's within the expected range you cited so that makes sense to be around 0.1% slower or so.
3. I agree I actually like the sound profile quite a bit since I can treat it as a starting point and filter it however I want in post :)

AidanHockey5, 2021-02-28:
Awesome! Yeah, 2% pitch change would have totally been noticeable at human scale, so I was super confused on that bit. If it’s only a tiny fraction of a cent off, that’s pretty much to be expected since it’s well within margin of error. I’m going to go ahead and close this issue now, but thanks for the insight!

Closed 2021-02-28.

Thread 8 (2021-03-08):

Loops: 1 = Loops: 0 and Loops: 0 just instantly switches through tracks.

birdybro, 2021-03-08:
Title kinda says it all. When I set Loops to 0, this ends up just cycling through tracks rapidly, sort of like it's `loops: -1` or something like that. If I set loops to 1, it acts as though there is no loop.

AidanHockey5, 2021-03-09:
That’s a fairly easy fix. I’ll just set the minimum loop value to 1 instead
of zero. Good catch!

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

AidanHockey5, 2021-03-13:
[Fixed here](https://github.com/AidanHockey5/MegaBlaster2/commit/b9249292348143ee4603d3a3c36aa7a3937c46f3), thank you!

Closed 2021-03-13.

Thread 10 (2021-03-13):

License change without other participants.

krsshtx, 2021-03-13:
Hi Aidan!

Megablaster was open. People used to build and test it, report bugs, share ideas, code.
You used them. Now you call this engine "new" but it's definitely not.
No one was credited in the code.
You changed license, permit selling and started selling for yourself.

Everything ok?

AidanHockey5, 2021-03-13:
Hello!
I’m not sure what you mean? The engine was indeed built from scratch this time around. It took about 7 months of development time. Probably the only major carry-over is the track info screen, but even that was changed a bit. The file system was also painstakingly programmed from scratch this time around.

I invite you to view the commit history of this project to see how it was developed over time. It’s all there.

Both the original MB and the MB2 were indeed solo projects, other than the libraries I utilized. My friend Natalie is probably the one I consulted with the most, and she gracefully offered one of her modified ring-buffer scripts as well as the constellation for analog stage. The latter of which she is literally credited on both sides of the board’s silk-screen front and back. That is who “Kunoichi” is.

The license is also exactly the same as the old MB. AGPL 3.0 for the code and CC-BY-NC-SA 4.0 for the hardware.  That is what I use for all of my projects. Users are more than welcome to create their own board for personal use, but I’m the only one permitted to sell them commercially, which I think is more than fair. This also allows contributions to the code-base should they ever arise.

I’m not entirely sure what your angle is with this issue, but I’m more than happy to answer any questions you may have.

krsshtx, 2021-03-13:
Hi!
I mean exactly this thread where you gave up and then appeared again.
I would like you to answer.

https://github.com/AidanHockey5/STM32_VGM_Player_YM2612_SN76489/issues/2

AidanHockey5, 2021-03-13:
Sure! At the time, I was convinced that I wouldn’t be able to solve that issue because I thought it was a hardware limitation rather than a software one.

The VGMEngine library I created was actually developed on the original MB before I began development on the MB2. I used the original MB as a prototyping platform, but the new engine worked so well that I decided to officially integrate it, even though the original MB was indeed end-of-life. I’m sorry that you seem to have been affected by this change in some way, but that’s progress. I even chose to integrate the new engine into my Throwback Operator OPL3 board too simply because I was so happy with how it turned out.

Also, keep in mind that posting code snippets in an issue isn’t exactly a contribution. You never submitted any pull-requests to contribute directly, therefore, I just considered your code as a separate fork that I wasn’t involved in. In-fact, nobody created any pull-requests for the original MB. Just to make things clear, your fork was not used as a reference in any way when developing my new engine, sorry.

krsshtx, 2021-03-13:
> Just to make things clear, your fork was not used as a reference in any way when developing my new engine, sorry.

And you never looked inside, didn't try it on hardware and never though why it works better?

AidanHockey5, 2021-03-13:
Sorry, can’t say that I did. Again, up until I made the new engine, I wasn’t planning on returning back to that project as there were a multitude of issues with the hardware as well (poorly routed, heavy analog interference, parts that are EOL, tiny RAM, etc.)
I apologize, but that’s the truth. For the MB2, I wanted a platform that was “done right,” so it was remade from scratch. The original MB is history to me at this point, but I figured I’d give those that bothered to create my project one last update since most of the work on it was already done.

krsshtx, 2021-03-13:
Since there is no difference to me between old parseVGM function and your "new" class VGMEngineClass except  while(waitSamples <= 0) and no waits
I consider this as a marvellous transformation and can't believe you.
Sorry. There are no wonders.

AidanHockey5, 2021-03-13:
...what are you even talking about? Did you even read the code? There are MASSIVE changes to how my old engine used to work.
https://github.com/AidanHockey5/MegaBlaster2/blob/master/lib/VGMEngine/VGMEngine.cpp

There is a completely new loader, buffer system, header parser, PCM loader, DAC stream processor, and state-machine. Of course the “waitSamples” line will look similar - it is literally part of the VGM specification to keep track of your wait samples before executing new commands.

Again, I still have no idea what your point is and this doesn’t seem to be an issue with the code, rather me personally for some reason. If you’d like to actually make a contribution, feel free to do so via a pull request, but if you’d like to continue to air your grievances towards me for what ever reason, I’d prefer if you’d just send me an email. https://www.aidanlawrence.com/contact/

krsshtx, 2021-03-13:
>the “waitSamples” line will look similar - it is literally part of the VGM specification to keep track of your wait samples before executing new commands.

But without this little word the whole device is a garbage.

And you didn't make it right. And gave up.
Any loader you use.

AidanHockey5, 2021-03-13:
Dude what lol

krsshtx, 2021-03-13:
>Dude what lol

That's all happened after natarii talk was over.

AidanHockey5, 2021-03-13:
This is probably the strangest “issue” I’ve ever seen haha
You seem to take issue with the fact that I learned something new and decided to integrate my new knowledge into an old project as a courtesy to those who decided to build the unit.

Feel free to do as you wish with your fork friend, but at this point, I’m not going to reply back to this thread. Again, sorry if you feel slighted in any way (...for some reason?) but I’m not interested in wasting more time on this.

If this is how you behave, I am not interested in your contributions.

krsshtx, 2021-03-13:
>If this is how you behave, I am not interested in your contributions.

I wrote here because you didn't reply in the other issue.
You don't answer emails.

You are too much in love with yourself.
It's a big delusion to think that I interested in contribution to a man who didn't mentioned anyone even in the code yet.
Very disappointed by you.

AidanHockey5, 2021-03-13:
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

Closed 2021-03-13.

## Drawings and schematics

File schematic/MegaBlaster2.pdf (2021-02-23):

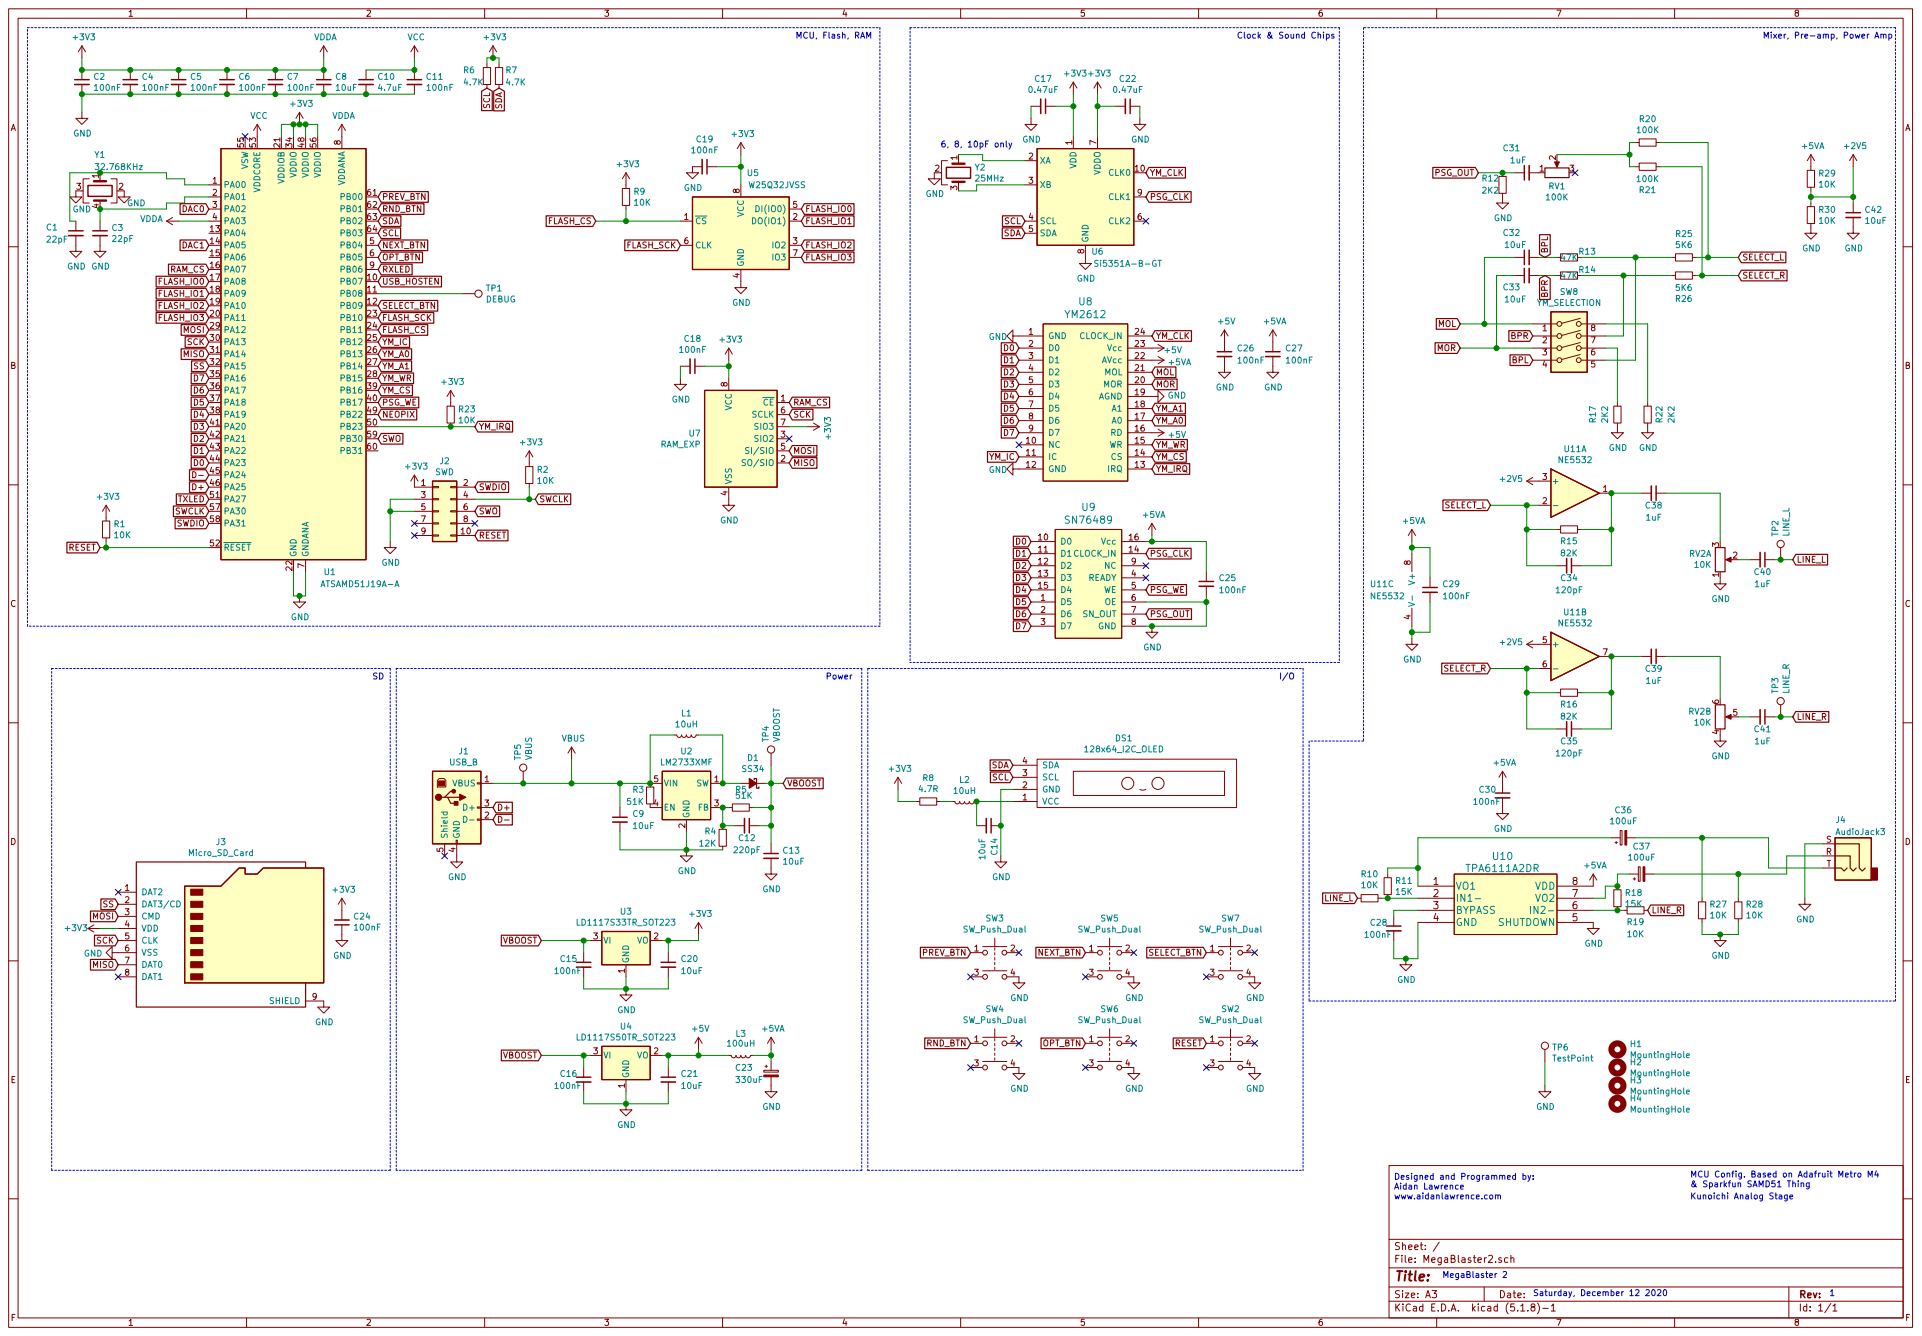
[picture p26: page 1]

1 CLK0 10 XA 2 XB 3 SCL 4 SDA 5 CLK2 6 VDDO

4 SI/SIO 5 SCLK 6 SIO3 7 VCC

Designed and Programmed by: Aidan Lawrence www.aidanlawrence.com

MCU Config. Based on Adafruit Metro M4
& Sparkfun SAMD51 Thing
Kunoichi Analog Stage

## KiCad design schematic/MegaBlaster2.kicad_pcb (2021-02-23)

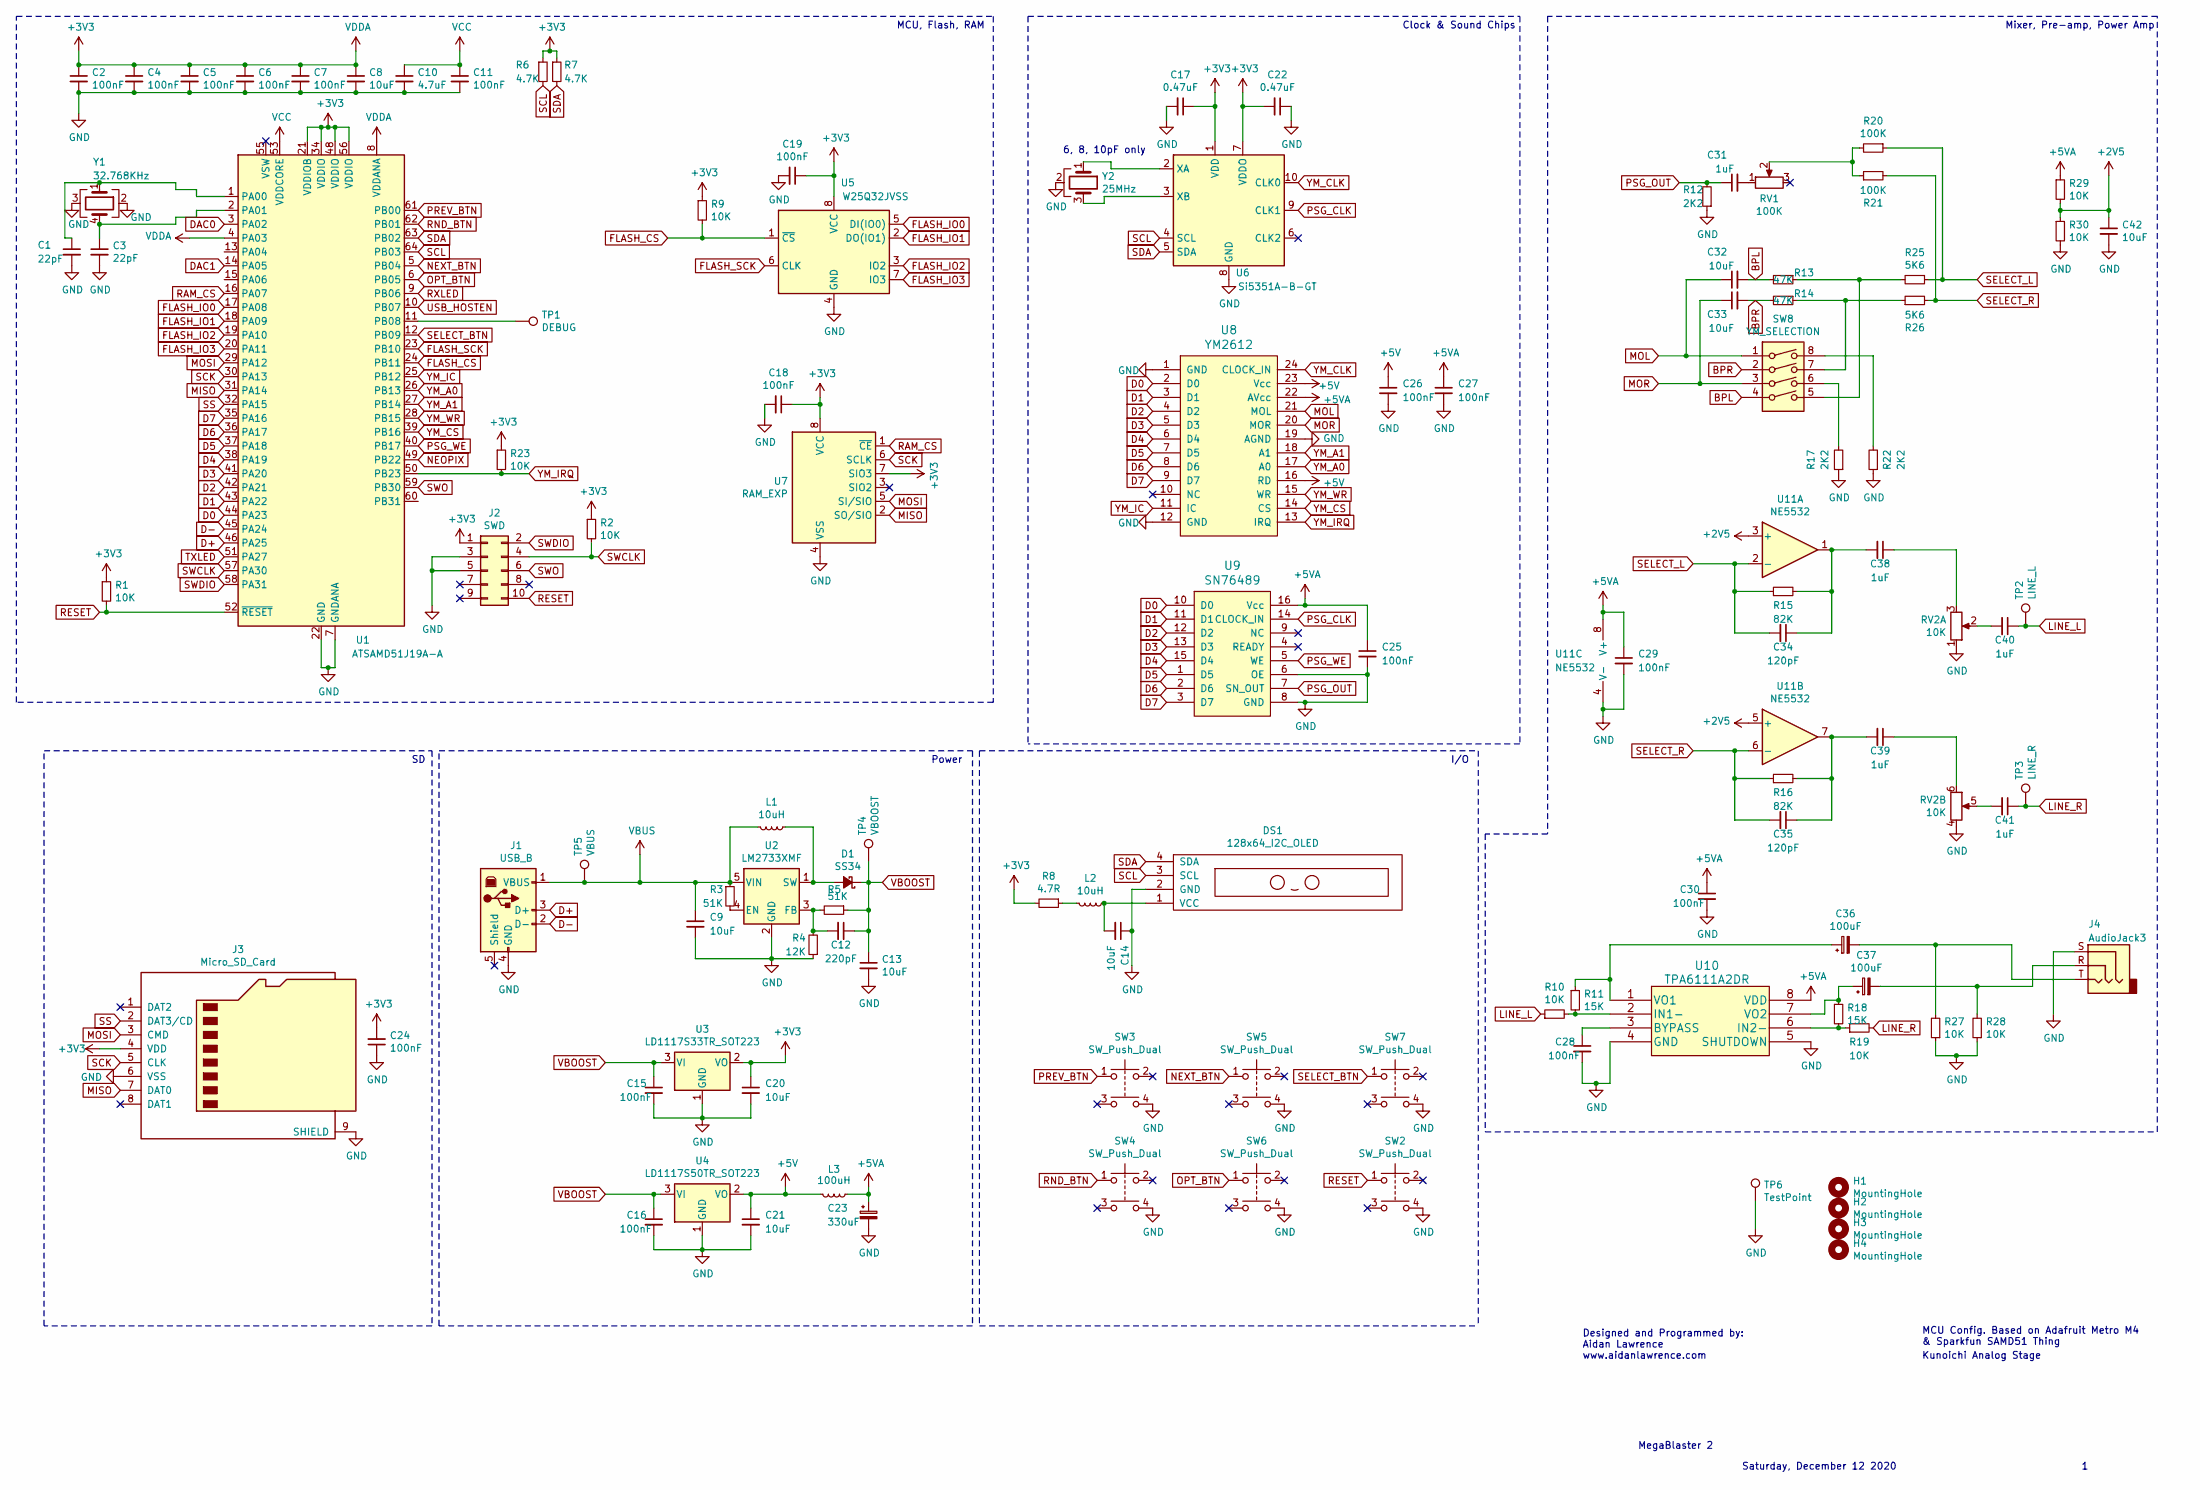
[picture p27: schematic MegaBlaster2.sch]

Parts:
C1, C3: 22pF; C_0603_1608Metric
C2, C4, C5, C6, C7, C11, C15, C16, C18, C19, C24, C25, C26, C27, C28, C29, C30: 100nF; C_0805_2012Metric
C8, C9, C13, C14, C20, C21, C32, C33, C42: 10uF; C_1206_3216Metric
C10: 4.7uF; C_0805_2012Metric
C12: 220pF; C_0603_1608Metric
C17, C22: 0.47uF; C_0805_2012Metric
C23: 330uF; CP_Elec_8x10
C31, C38, C39, C40, C41: 1uF; C_0805_2012Metric
C34, C35: 120pF; C_0603_1608Metric
C36, C37: 100uF; CP_Elec_6.3x7.7
D1: SS34; D_SMA
DS1: 128x64_I2C_OLED; oled_128x64
H1, H2, H3, H4: MountingHole; MountingHole_3.2mm_M3
J1: USB_B; USB_B_Lumberg_2411_02_Horizontal
J2: SWD; PinHeader_2x05_P1.27mm_Vertical
J3: Micro_SD_Card; SOFNG_TF_15x15_PUSH_PUSH
J4: AudioJack3; SWITCHCRAFT_35RAPC4BHN2
L1, L2: 10uH; L_4x4
L3: 100uH; 6x6Inductor
R1, R2, R9, R10, R19, R23, R27, R28, R29, R30: 10K; R_0805_2012Metric
R3, R5: 51K; R_0805_2012Metric
R4: 12K; R_0805_2012Metric
R6, R7: 4.7K; R_0805_2012Metric
R8: 4.7R; R_0805_2012Metric
R11, R18: 15K; R_0805_2012Metric
R12, R17, R22: 2K2; R_0805_2012Metric
R13, R14: 47K; R_0805_2012Metric
R15, R16: 82K; R_0805_2012Metric
R20, R21: 100K; R_0805_2012Metric
R25, R26: 5K6; R_0805_2012Metric
RV1: 100K; 3362P-1-103LF
RV2: 10K; Potentiometer_Alps_RK097_Dual_Horizontal
SW2, SW3, SW4, SW5, SW6, SW7: SW_Push_Dual; SW_TH_Tactile_Omron_B3F-10xx
SW8: YM_SELECTION; SW_DIP_SPSTx04_Slide_9.78x12.34mm_W7.62mm_P2.54mm
TP1: DEBUG; TestPoint_Pad_D2.0mm
TP2: LINE_L; TestPoint_Pad_D2.0mm
TP3: LINE_R; TestPoint_Pad_D2.0mm
TP4: VBOOST; TestPoint_Pad_D2.0mm
TP5: VBUS; TestPoint_Pad_D2.0mm
TP6: TestPoint; TestPoint_Pad_2.0x2.0mm
U1: ATSAMD51J19A-A; TQFP-64_10x10mm_P0.5mm
U2: LM2733XMF; SOT-23-5
U3: LD1117S33TR_SOT223; SOT-223-3_TabPin2
U4: LD1117S50TR_SOT223; SOT-223-3_TabPin2
U5: W25Q32JVSS; SOIC-8_5.23x5.23mm_P1.27mm
U6: Si5351A-B-GT; MSOP-10_3x3mm_P0.5mm
U7: RAM_EXP; SOIC-8_3.9x4.9mm_P1.27mm
U8: YM2612; DIP-24_W15.24mm_Socket
U9: SN76489; DIP-16_W7.62mm_Socket
U10: TPA6111A2DR; SOIC-8_3.9x4.9mm_P1.27mm
U11: NE5532; SOIC-8_3.9x4.9mm_P1.27mm
Y1: 32.768KHz; Crystal_SMD_SeikoEpson_MC306-4Pin_8.0x3.2mm
Y2: 25MHz; Crystal_SMD_3225-4Pin_3.2x2.5mm

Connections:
+2V5: C42.1, R29.2, R30.1, U11.3 (+), U11.5 (+)
+3V3: C2.1, C4.1, C5.1, C6.1, C7.1, C8.1, C17.1, C18.1, C19.1, C20.1, C22.2, C24.2, J2.1, J3.4 (VDD), R1.1, R2.1, R6.1, R7.1, R8.2, R9.1, R23.1, U1.4 (PA03), U1.8 (VDDANA), U1.21 (VDDIOB), U1.34 (VDDIO), U1.48 (VDDIO), U1.56 (VDDIO), U3.2 (VO), U5.8 (VCC), U6.1 (VDD), U6.7 (VDDO), U7.7 (SIO3), U7.8 (VCC)
+5V: C21.1, C26.1, L3.2, U4.2 (VO), U8.16 (RD), U8.23 (Vcc)
+5VA: C23.1, C25.1, C27.1, C29.1, C30.1, L3.1, R29.1, U8.22 (AVcc), U9.16 (Vcc), U10.8 (VDD), U11.8 (V+)
BPL: C32.2, R13.2, SW8.4
BPR: C33.2, R14.2, SW8.2
D0: U1.44 (PA23), U8.2 (D0), U9.10 (D0)
D1: U1.43 (PA22), U8.3 (D1), U9.11 (D1)
D2: U1.42 (PA21), U8.4 (D2), U9.12 (D2)
D3: U1.41 (PA20), U8.5 (D3), U9.13 (D3)
D4: U1.38 (PA19), U8.6 (D4), U9.15 (D4)
D5: U1.37 (PA18), U8.7 (D5), U9.1 (D5)
D6: U1.36 (PA17), U8.8 (D6), U9.2 (D6)
D7: U1.35 (PA16), U8.9 (D7), U9.3 (D7)
D+: J1.3 (D+), U1.46 (PA25)
D-: J1.2 (D-), U1.45 (PA24)
DAC0: U1.3 (PA02)
DAC1: U1.14 (PA05)
FLASH_CS: R9.2, U1.24 (PB11), U5.1 (~CS)
FLASH_IO0: U1.17 (PA08), U5.5 (DI(IO0))
FLASH_IO1: U1.18 (PA09), U5.2 (DO(IO1))
FLASH_IO2: U1.19 (PA10), U5.3 (IO2)
FLASH_IO3: U1.20 (PA11), U5.7 (IO3)
FLASH_SCK: U1.23 (PB10), U5.6 (CLK)
GND: C1.2, C2.2, C3.2, C4.2, C5.2, C6.2, C7.2, C8.2, C9.2, C10.2, C11.2, C13.2, C14.1, C15.2, C16.2, C17.2, C18.2, C19.2, C20.2, C21.2, C22.1, C23.2, C24.1, C25.2, C26.2, C27.2, C28.2, C29.2, C30.2, C42.2, DS1.2 (GND), J1.4 (GND), J2.3, J2.5, J3.6 (VSS), J3.9 (SHIELD), J4.S, R4.1, R12.1, R17.1, R22.1, R27.1, R28.1, R30.2, RV2.1 (6), RV2.4, SW2.4, SW3.4, SW4.4, SW5.4, SW6.4, SW7.4, TP6.1, U1.7 (GNDANA), U1.22 (GND), U1.33 (GND), U1.47 (GND), U1.54 (GND), U2.2 (GND), U3.1 (GND), U4.1 (GND), U5.4 (GND), U6.8 (GND), U7.4 (VSS), U8.1 (GND), U8.12 (GND), U8.19 (AGND), U9.6 (OE), U9.8 (GND), U10.4 (GND), U10.5 (SHUTDOWN), U11.4 (V-), Y1.2, Y1.3, Y2.2
LINE_L: C40.1, R10.1, TP2.1
LINE_R: C41.1, R19.2, TP3.1
MISO: J3.7 (DAT0), U1.31 (PA14), U7.2 (SO/SIO)
MOL: C32.1, SW8.1, U8.21 (MOL)
MOR: C33.1, SW8.3, U8.20 (MOR)
MOSI: J3.3 (CMD), U1.29 (PA12), U7.5 (SI/SIO)
NEOPIX: U1.49 (PB22)
NEXT_BTN: SW5.1, U1.5 (PB04)
unnamed: C1.1, U1.1 (PA00), Y1.1
unnamed: C3.1, U1.2 (PA01), Y1.4
unnamed: C12.2, R4.2, R5.2, U2.3 (FB)
unnamed: C14.2, DS1.1 (VCC), L2.1
unnamed: C28.1, U10.3 (BYPASS)
unnamed: C31.2, RV1.1
unnamed: C34.1, C38.2, R15.2, U11.1
unnamed: C35.1, C39.2, R16.2, U11.7
unnamed: C36.1, R11.1, U10.1 (VO1)
unnamed: C36.2, J4.T, R27.2
unnamed: C37.1, R18.1, U10.7 (VO2)
unnamed: C37.2, J4.R, R28.2
unnamed: C38.1, RV2.3 (4)
unnamed: C39.1, RV2.6
unnamed: C40.2, RV2.2
unnamed: C41.2, RV2.5
unnamed: D1.2 (A), L1.1, U2.1 (SW)
unnamed: L2.2, R8.1
unnamed: R3.2, U2.4 (EN)
unnamed: R10.2, R11.2, U10.2 (IN1-)
unnamed: R13.1, R25.2, SW8.5
unnamed: R14.1, R26.1, SW8.7
unnamed: R17.2, SW8.6
unnamed: R18.2, R19.1, U10.6 (IN2-)
unnamed: R20.2, R21.1, RV1.2
unnamed: R22.2, SW8.8
unnamed: TP1.1, U1.11 (PB08)
unnamed: U6.2 (XA), Y2.1
unnamed: U6.3 (XB), Y2.3
OPT_BTN: SW6.1, U1.6 (PB05)
PREV_BTN: SW3.1, U1.61 (PB00)
PSG_CLK: U6.9 (CLK1), U9.14 (CLOCK_IN)
PSG_OUT: C31.1, R12.2, U9.7 (SN_OUT)
PSG_WE: U1.40 (PB17), U9.5 (WE)
RAM_CS: U1.16 (PA07), U7.1 (~CE)
RESET: J2.10, R1.2, SW2.1, U1.52 (~RESET)
RND_BTN: SW4.1, U1.62 (PB01)
RXLED: U1.9 (PB06)
SCK: J3.5 (CLK), U1.30 (PA13), U7.6 (SCLK)
SCL: DS1.3 (SCL), R6.2, U1.64 (PB03), U6.4 (SCL)
SDA: DS1.4 (SDA), R7.2, U1.63 (PB02), U6.5 (SDA)
SELECT_BTN: SW7.1, U1.12 (PB09)
SELECT_L: C34.2, R15.1, R20.1, R25.1, U11.2 (-)
SELECT_R: C35.2, R16.1, R21.2, R26.2, U11.6 (-)
SS: J3.2 (DAT3/CD), U1.32 (PA15)
SWCLK: J2.4, R2.2, U1.57 (PA30)
SWDIO: J2.2, U1.58 (PA31)
SWO: J2.6, U1.59 (PB30)
TXLED: U1.51 (PA27)
USB_HOSTEN: U1.10 (PB07)
VBOOST: C12.1, C13.1, C15.1, C16.1, D1.1 (K), R5.1, TP4.1, U3.3 (VI), U4.3 (VI)
VBUS: C9.1, J1.1 (VBUS), L1.2, R3.1, TP5.1, U2.5 (VIN)
VCC: C10.1, C11.1, U1.53 (VDDCORE)
YM_A0: U1.26 (PB13), U8.17 (A0)
YM_A1: U1.27 (PB14), U8.18 (A1)
YM_CLK: U6.10 (CLK0), U8.24 (CLOCK_IN)
YM_CS: U1.39 (PB16), U8.14 (CS)
YM_IC: U1.25 (PB12), U8.11 (IC)
YM_IRQ: R23.2, U1.50 (PB23), U8.13 (IRQ)
YM_WR: U1.28 (PB15), U8.15 (WR)

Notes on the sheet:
Designed and Programmed by: Aidan Lawrence www.aidanlawrence.com
MCU Config. Based on Adafruit Metro M4 & Sparkfun SAMD51 Thing
MegaBlaster 2
Saturday, December 12 2020
6, 8, 10pF only
Kunoichi Analog Stage
MCU, Flash, RAM
Clock & Sound Chips
Mixer, Pre-amp, Power Amp
I/O
Power

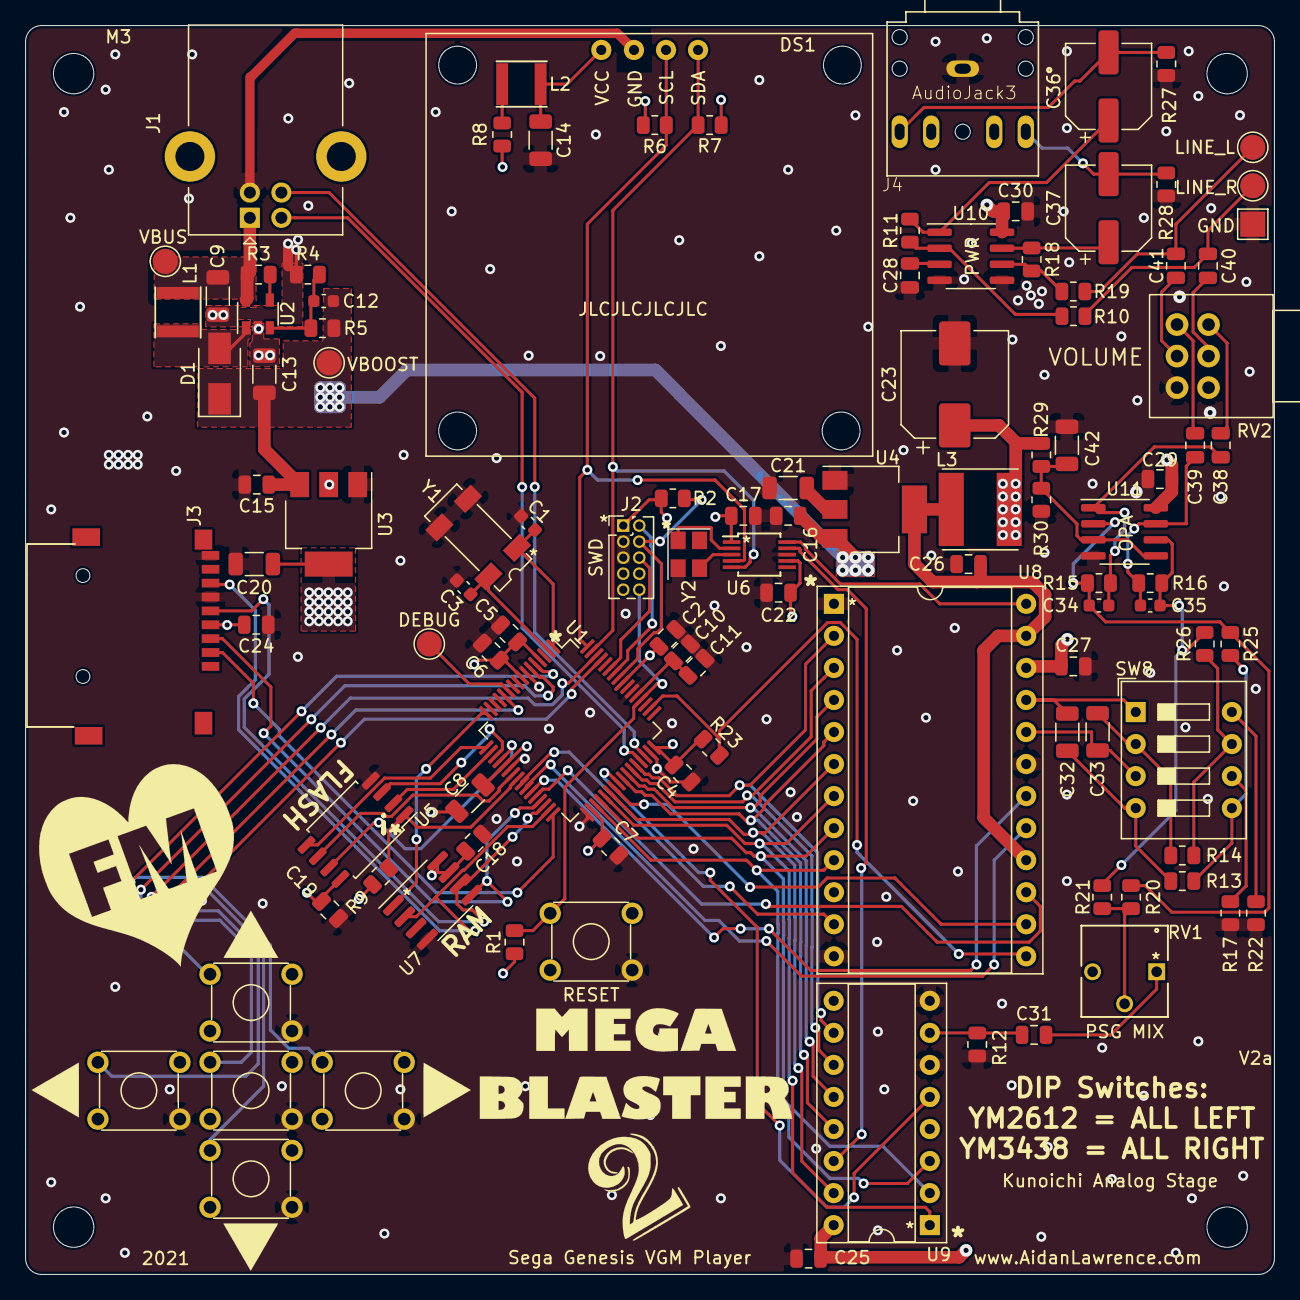
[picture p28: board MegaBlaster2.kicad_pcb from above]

Board: 4 copper layers, 99.0 x 99.0 mm, 112 parts (0 on the bottom side), 87 nets.

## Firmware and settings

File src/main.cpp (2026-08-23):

//SPI SD CARD LIBRARY WARNING:
//CHIP SELECT FEATURES MANUALLY ADJUSTED IN SDFAT LIB (in SdSpiDriver.h). MUST USE LIB INCLUDED WITH REPO!!!

#define BOOTLOADER_VERSION "1.0"
#define FIRMWARE_VERSION "1.29"

#include <Arduino.h>
#include <SPI.h>
#include <Wire.h>
#include "SdFat.h"
#include "U8g2lib.h"
#include "menu.h"
#include "menuIO/serialIO.h"
#include "plugin/SdFatMenu.h"
#include "menuIO/u8g2Out.h"
#include "YM2612.h"
#include "SN76489.h"
#include "Adafruit_ZeroTimer.h"
#include "logo.h"
#include "SpinSleep.h"
#include "SerialUtils.h"
#include "clocks.h"
#include "Bounce2.h"
#include "LinkedList.h"
#include "logo.h"
#include "decompress.h"
#include "FreeMem.h"

extern "C" {
  #include "trngFunctions.h" //True random number generation
}

#include "VGMEngine.h"

//Debug variables
#define DEBUG true //Set this to true for a detailed printout of the header data & any errored command bytes
#define DEBUG_LED A4
bool commandFailed = false;
uint8_t failedCmd = 0x00;
#define DISABLE_IRQ_TEST false

//Structs
enum FileStrategy {FIRST_START, NEXT, PREV, RND, REQUEST};
enum PlayMode {LOOP, PAUSE, SHUFFLE_ALL, IN_ORDER, SHUFFLE_DIR};
enum MenuState {IN_MENU, IN_VGM};

//Prototypes
void setup();
void loop();
void handleSerialIn();
void tick44k1();
void set44k1ISR();
void stop44k1();
void handleButtons();
void prepareChips();
void readGD3();
void drawOLEDTrackInfo();
bool startTrack(FileStrategy fileStrategy, String request = "");
bool vgmVerify();
void showIndexProgressOLED();
void findTracksOnRoot();
uint8_t VgmCommandLength(uint8_t Command);
uint32_t countFilesInDir(String dir); 
uint32_t getFileIndexInDir(String dir, String fname, uint32_t dirSize = 0);
String getFilePathFromCurrentDirFileIndex();
uint32_t readFile32(FatFile *f);
String readStringUntil(String & in, char terminator);
void getDirIndices(String dir, String fname);
void getDirIndicesFromFullPath(String fullPath);
uint32_t freeKB();
result filePick(eventMask event, navNode& _nav, prompt &item);
result onMenuIdle(menuOut& o, idleEvent e);
result onChoosePlaymode(eventMask e,navNode& _nav,prompt& item);
void removeMeta();
void clearRandomHistory();
void IRQ_ISR();
void IRQSelfTest();
void alertErrorState();

const uint32_t MANIFEST_MAGIC = 0x12345678; //Depricated
#define MANIFEST_FILE_NAME ".MANIFEST" //Depricated
#define SYS_DIR "_SYS/"
#define MANIFEST_PATH SYS_DIR MANIFEST_FILE_NAME //Depricated
#define TMP_DECOMPRESSION_FILE_PATH "/" SYS_DIR "/TMP.vgm"

//SD & File Streaming
SdFat SD;
static File file;
#define MAX_FILE_NAME_SIZE 128
char fileName[MAX_FILE_NAME_SIZE];
uint32_t numberOfFiles = 0;
uint32_t numberOfDirectories = 0;
String currentDir = "";
uint32_t currentDirFileCount = 0;
uint32_t currentDirFileIndex = 0;
uint32_t currentDirDirCount = 0; //How many directories are IN the current directory, mainly used for root only.
uint32_t rootObjectCount = 0; //How many objects (files and folders) are in the root directory

uint32_t dirStartIndex, dirEndIndex, dirCurIndex = 0; //indicies that mark the beginning, end, and current location inside of a dir
LinkedList<int> rootTrackIndicies = LinkedList<int>(); //Valid VGM/VGZ file indicies on the root are stored here
LinkedList<int> randFileList = LinkedList<int>(); //Used to keep a history of file indices when in shuffle mode to allow for forward/backwards playback controls
LinkedList<String> randDirList = LinkedList<String>();
int randIndex = 0; 
#define MAX_RAND_HISTORY_SIZE 20

Adafruit_ZeroTimer timer1 = Adafruit_ZeroTimer(3);
Adafruit_ZeroTimer timer2 = Adafruit_ZeroTimer(4);
//SAMDTimer ITimer(TIMER_TC3);
//SAMDTimer dacStreamTimer(MAX_TIMER);

Bus bus(0, 1, 8, 9, 11, 10, 12, 13);

YM2612 opn(&bus, 3, NULL, 6, 4, 5, 7);
SN76489 sn(&bus, 2);
const uint8_t IRQTestPin = 51;

//VGM Variables
uint16_t loopCount = 0;
uint8_t maxLoops = 3;
bool fetching = false;
volatile bool ready = false;
bool samplePlaying = false;
PlayMode playMode = IN_ORDER;
bool doParse = false;

//UI & Menu
U8G2_SH1106_128X64_NONAME_F_HW_I2C u8g2(U8G2_R0);
#define fontName u8g2_font_6x12_mr     
#define fontX 6
#define fontY 14
#define offsetX 0
#define offsetY 0
#define U8_Width 128
#define U8_Height 64
const colorDef<uint8_t> colors[6] MEMMODE={
  {{0,0},{0,1,1}},//bgColor
  {{1,1},{1,0,0}},//fgColor
  {{1,1},{1,0,0}},//valColor
  {{1,1},{1,0,0}},//unitColor
  {{0,1},{0,0,1}},//cursorColor
  {{1,1},{1,0,0}},//titleColor
};

using namespace Menu;
SDMenuT<CachedFSO<SdFat,32>> filePickMenu(SD,"Music","/",filePick,enterEvent);

CHOOSE(playMode,modeMenu,"Mode:",onChoosePlaymode,exitEvent,noStyle
  ,VALUE("Loop",PlayMode::LOOP,doNothing,noEvent)
  ,VALUE("In Order",PlayMode::IN_ORDER,doNothing,noEvent)
  ,VALUE("Shuffle All",PlayMode::SHUFFLE_ALL,doNothing,noEvent)
  ,VALUE("Shuffle Dir",PlayMode::SHUFFLE_DIR,doNothing,noEvent)
);

TOGGLE(VGMEngine.loopOneOffs, setLoopOneOff, "Loop One-offs: ", doNothing, noEvent, noStyle
    ,VALUE("ON",true,doNothing,noEvent)
    ,VALUE("OFF",false,doNothing,noEvent)
);

TOGGLE(VGMEngine.isSyncToneEnabled, setSyncToneToggle, "Sync-tone: ", doNothing, noEvent, noStyle
    ,VALUE("ON",true,doNothing,noEvent)
    ,VALUE("OFF",false,doNothing,noEvent)
);

TOGGLE(VGMEngine.ym2612CHControl[0x00], setYM2612CH1, "FM CH1: ", doNothing, noEvent, noStyle
    ,VALUE("ON",true,doNothing,noEvent)
    ,VALUE("OFF",false,doNothing,noEvent)
);

TOGGLE(VGMEngine.ym2612CHControl[0x01], setYM2612CH2, "FM CH2: ", doNothing, noEvent, noStyle
    ,VALUE("ON",true,doNothing,noEvent)
    ,VALUE("OFF",false,doNothing,noEvent)
);

TOGGLE(VGMEngine.ym2612CHControl[0x02], setYM2612CH3, "FM CH3: ", doNothing, noEvent, noStyle
    ,VALUE("ON",true,doNothing,noEvent)
    ,VALUE("OFF",false,doNothing,noEvent)
);

TOGGLE(VGMEngine.ym2612CHControl[0x03], setYM2612CH4, "FM CH4: ", doNothing, noEvent, noStyle //was this 0x04 for a reason or just a typo?
    ,VALUE("ON",true,doNothing,noEvent)
    ,VALUE("OFF",false,doNothing,noEvent)
);

TOGGLE(VGMEngine.ym2612CHControl[0x04], setYM2612CH5, "FM CH5: ", doNothing, noEvent, noStyle
    ,VALUE("ON",true,doNothing,noEvent)
    ,VALUE("OFF",false,doNothing,noEvent)
);

TOGGLE(VGMEngine.ym2612CHControl[0x05], setYM2612CH6, "FM CH6: ", doNothing, noEvent, noStyle
    ,VALUE("ON",true,doNothing,noEvent)
    ,VALUE("OFF",false,doNothing,noEvent)
);

TOGGLE(VGMEngine.sn76489CHControl[0x00], setSN76489CH1, "PSG CH1: ", doNothing, noEvent, noStyle
    ,VALUE("ON",true,doNothing,noEvent)
    ,VALUE("OFF",false,doNothing,noEvent)
);

TOGGLE(VGMEngine.sn76489CHControl[0x01], setSN76489CH2, "PSG CH2: ", doNothing, noEvent, noStyle
    ,VALUE("ON",true,doNothing,noEvent)
    ,VALUE("OFF",false,doNothing,noEvent)
);

TOGGLE(VGMEngine.sn76489CHControl[0x02], setSN76489CH3, "PSG CH3: ", doNothing, noEvent, noStyle
    ,VALUE("ON",true,doNothing,noEvent)
    ,VALUE("OFF",false,doNothing,noEvent)
);

TOGGLE(VGMEngine.sn76489CHControl[0x03], setSN76489CH4, "PSG CH4: ", doNothing, noEvent, noStyle
    ,VALUE("ON",true,doNothing,noEvent)
    ,VALUE("OFF",false,doNothing,noEvent)
);

MENU(channelControl,"Channel Control",doNothing,noEvent,wrapStyle
  ,SUBMENU(setYM2612CH1)
  ,SUBMENU(setYM2612CH2)
  ,SUBMENU(setYM2612CH3)
  ,SUBMENU(setYM2612CH4)
  ,SUBMENU(setYM2612CH5)
  ,SUBMENU(setYM2612CH6)
  ,SUBMENU(setSN76489CH1)
  ,SUBMENU(setSN76489CH2)
  ,SUBMENU(setSN76489CH3)
  ,SUBMENU(setSN76489CH4)
);

#define MAX_DEPTH 2
MENU(mainMenu,"Main menu",doNothing,noEvent,wrapStyle
  ,SUBMENU(filePickMenu)
  ,SUBMENU(modeMenu)
  ,FIELD(VGMEngine.maxLoops,"Loops: ","",1,255,1,10,doNothing,noEvent,noStyle)
  ,SUBMENU(setLoopOneOff)
  ,SUBMENU(channelControl)
  ,SUBMENU(setSyncToneToggle)
  //,EXIT("<Back")
);

MENU_OUTPUTS(out,MAX_DEPTH
  ,U8G2_OUT(u8g2,colors,fontX,fontY,offsetX,offsetY,{0,0,U8_Width/fontX,U8_Height/fontY})
  //,U8X8_OUT(u8x8,{0,0,16,8}) //0,0 Char# x y
  //,SERIAL_OUT(Serial)
  ,NONE//must have 2 items at least
);
serialIn serial(Serial);
NAVROOT(nav,mainMenu,MAX_DEPTH,serial,out);

MenuState menuState = IN_MENU;
#define MENU_TIMEOUT_IN_SECONDS 10

bool isOledOn = true;

//Buttons
const int prev_btn = 47;    //PORT_PB00;
const int down_btn = 48;    //PORT_PB01;
const int next_btn = 49;    //PORT_PB04;
const int up_btn = 50;  //PORT_PB05;
const int select_btn = 19;  //PORT_PB09;
Bounce buttons[5];

//Counters
uint32_t bufferPos = 0;
uint32_t cmdPos = 0;
uint16_t waitSamples = 0;
uint32_t pcmBufferPosition = 0;

void TC3_Handler() 
{
  Adafruit_ZeroTimer::timerHandler(3);
}

void TC4_Handler() 
{
  Adafruit_ZeroTimer::timerHandler(4);
}

void tick44k1(void) //44.1KHz tick
{
  VGMEngine.tick44k1();
}

void stop44k1()
{
  timer1.enable(false);
}

void set44k1ISR()
{
  //44.1KHz target, actual 44,117Hz
  const uint16_t compare = 1088;
  tc_clock_prescaler prescaler = TC_CLOCK_PRESCALER_DIV1;
  timer1.enable(false);
  timer1.configure(prescaler,       // prescaler
        TC_COUNTER_SIZE_16BIT,       // bit width of timer/counter
        TC_WAVE_GENERATION_MATCH_PWM // frequency or PWM mode
        );
  timer1.setCompare(0, compare);
  timer1.setCallback(true, TC_CALLBACK_CC_CHANNEL0, tick44k1);
  timer1.enable(true);
}

void tickDacStream()
{
  VGMEngine.tickDacStream();
}

void stopDacStreamTimer()
{
  timer2.enable(false);
}

void setDacStreamTimer(uint32_t frequency)
{
  float prescale = 1;
  float period = (1000000.0f / frequency);
  float compare = (48000000L / (prescale/(period/1000000L)))-1;

  tc_clock_prescaler prescaler = TC_CLOCK_PRESCALER_DIV1;
  timer2.enable(false);
  timer2.configure(prescaler,       // prescaler
        TC_COUNTER_SIZE_16BIT,       // bit width of timer/counter
        TC_WAVE_GENERATION_MATCH_PWM // frequency or PWM mode
        );
  timer2.setCompare(0, compare);
  timer2.setCallback(true, TC_CALLBACK_CC_CHANNEL0, tickDacStream);
  timer2.enable(true);
  //Serial.println(frequency);
}

void setup()
{
  //COM
  Wire.begin();
  Wire.setClock(600000L);
  SPI.begin();
  Serial.begin(115200);

  if(!si5351.init(SI5351_CRYSTAL_LOAD_8PF, 0, 0)) //Can't find clock gen at 0x6F? Reassign to 0x60 and try again to see if 'A' variant is installed.
  {
    si5351 = si5351A;
    si5351.init(SI5351_CRYSTAL_LOAD_8PF, 0, 0);
  }
  si5351.drive_strength(SI5351_CLK0, SI5351_DRIVE_4MA);
  si5351.drive_strength(SI5351_CLK1, SI5351_DRIVE_4MA);
  si5351.set_freq(NTSC_YMCLK*100ULL, SI5351_CLK0); //CLK0 YM
  si5351.set_freq(NTSC_COLORBURST*100ULL, SI5351_CLK1); //CLK1 PSG - VALUES IN 0.01Hz

  //Timers
  VGMEngine.setDacStreamTimer = &setDacStreamTimer;
  VGMEngine.stopDacStreamTimer = &stopDacStreamTimer;

  //RNG
  trngInit();
  //randomSeed(trngGetRandomNumber());

  //DEBUG
  //pinMode(DEBUG_LED, INPUT_PULLUP);
  pinMode(IRQTestPin, INPUT);

  resetSleepSpin();

  //Button configs
  for(uint8_t i = 0; i<5; i++)
  {
    buttons[i] = Bounce();
    buttons[i].interval(25);
  }
  buttons[0].attach(next_btn, INPUT_PULLUP);
  buttons[1].attach(prev_btn, INPUT_PULLUP);
  buttons[2].attach(up_btn, INPUT_PULLUP);
  buttons[3].attach(select_btn, INPUT_PULLUP);
  buttons[4].attach(down_btn, INPUT_PULLUP);

  //Set Chips
  VGMEngine.ym2612 = &opn;
  VGMEngine.sn76489 = &sn;

  opn.reset();
  sn.reset();

  //u8g2 OLED
  u8g2.begin();
  u8g2.setBusClock(600000);
  u8g2.setFont(fontName);

  #if !DISABLE_IRQ_TEST
  IRQSelfTest(); //Test the OPN via it's timers to make sure it's legit
  #endif

  //OLED title logo
  u8g2.drawXBM(0,0, logo_width, logo_height, logo);
  const String bootloaderFWVersion = "BL: " + String(BOOTLOADER_VERSION) + " FW: " + String(FIRMWARE_VERSION) + " 2021";
  u8g2.drawStr(0, 64, bootloaderFWVersion.c_str());
  u8g2.sendBuffer();
  delay(3000);
  u8g2.clearDisplay();

  //SD
  REG_PORT_DIRSET0 = PORT_PA15; //Set PA15 to output
  if(!SD.begin(PORT_PA15, SPI_FULL_SPEED))
  {
    Serial.println("SD Mount Failed!");
    u8g2.clearBuffer();
    u8g2.drawStr(0,16,"SD Mount");
    u8g2.drawStr(0,32,"failed!");
    u8g2.sendBuffer();
    while(true){Serial.println("SD MOUNT FAILED"); delay(1000);}
  }
  filePickMenu.begin();
  nav.useAccel=true;
  options->invertFieldKeys = true;

  Serial.flush();

  //Prepare files
  if(!SD.exists(SYS_DIR))
    SD.mkdir(SYS_DIR);

  rootObjectCount = countFilesInDir("/");
  findTracksOnRoot();

  nav.timeOut=0xFFFFFFFF; //This might be a slight issue if you decide to run your player for 50,000 days straight :/
  nav.idleTask = onMenuIdle;
}

uint16_t IRQtestCounter = 0;
void IRQ_ISR()
{
  opn.setYMTimerA(0);
  IRQtestCounter++;
}

void IRQSelfTest() //Use the IRQ pin and the built-in OPN timers to determine if a real chip has been installed (correctly)
{
  Serial.println("Testing IRQ...");
  attachInterrupt(digitalPinToInterrupt(IRQTestPin), IRQ_ISR, FALLING);
  opn.setYMTimerA(0);
  unsigned long s = millis();
  while(true)
  {
    if(millis()-s > 1000) //Warn user to power device down as their chip may be fake and cause damage to the rest of the system
    {
      //fail
      //https://ww1.microchip.com/downloads/en/DeviceDoc/SAM_D5x_E5x_Family_Data_Sheet_DS60001507G.pdf page 805, perhaps tri-state all of the pins?
      Serial.println("DANGER!!! YM2612/YM3438 NOT DETECTED! POWER DOWN AND REMOVE IC!");
      u8g2.clear();
      u8g2.drawStr(0, 10, "DANGER! UNPLUG UNIT!");
      u8g2.drawStr(0, 20, "YM2612/YM3438");
      u8g2.drawStr(0, 30, "NOT DETECTED!");
      u8g2.drawStr(0, 40, "Your chip may be fake");
      u8g2.drawStr(0, 51, "or seated incorrectly.");
      u8g2.drawStr(0, 62, "Halting...");
      u8g2.sendBuffer();
      while(true);
    }
    if(IRQtestCounter >= 10) //The IRQ pin has pulsed 10 times, it's probably a real chip
    {
      break;
    }
  };
  Serial.println("YM IRQ OK!");
  detachInterrupt(digitalPinToInterrupt(IRQTestPin));
  opn.clearYMTimerA();
}

void drawOLEDTrackInfo()
{
  if(isOledOn)
  {
    u8g2.clearBuffer();
    u8g2.setDrawColor(1);
    u8g2.setPowerSave(0);
    u8g2.clearDisplay();
    u8g2.setFont(u8g2_font_helvR08_tr);
    u8g2.sendBuffer();
    if(wstrlen(VGMEngine.gd3.enTrackName) != 1) //No track name was seen in the GD3
    {
      u8g2.drawStr(0,10, widetochar(VGMEngine.gd3.enTrackName));
      u8g2.drawStr(0,20, widetochar(VGMEngine.gd3.enGameName));
      u8g2.drawStr(0,30, widetochar(VGMEngine.gd3.releaseDate));
      u8g2.drawStr(0,40, widetochar(VGMEngine.gd3.enSystemName));
    }
    else
    {
      u8g2.drawStr(0,10, "No GD3 Data");
    }

    char* cstr;
    String playmodeStatus;
    if(playMode == LOOP)
      playmodeStatus = "LOOP";
    else if(playMode == SHUFFLE_ALL)
      playmodeStatus = "SHUFFLE ALL";
    else if(playMode == SHUFFLE_DIR)
      playmodeStatus = "SHUFFLE DIR";
    else if(playMode == IN_ORDER)
    {
      String fileNumberData = "Track: " + String(dirCurIndex-dirStartIndex) + "/" + String(dirEndIndex-dirStartIndex); 
      cstr = &fileNumberData[0u];
      u8g2.drawStr(0,50, cstr);
      playmodeStatus = "IN ORDER";
    }
    cstr = &playmodeStatus[0u];
    u8g2.drawStr(0, 60, cstr);
    u8g2.sendBuffer();
  }
  else
  {
    u8g2.clearDisplay();
    u8g2.setPowerSave(1);
    u8g2.sendBuffer();
  }
  u8g2.setFont(fontName);
}

void findTracksOnRoot()
{
  SD.chdir("/");
  File tmp;
  for(uint32_t i = 0; i<rootObjectCount; i++)
  {
    tmp.close();
    tmp.openNext(SD.vwd(), O_READ);
    if(!tmp.isDirectory())
    {
      if(VGMEngine.header.read(&tmp))
      {
        rootTrackIndicies.add(i);
      }
      else
      {
        uint16_t gzipmagic = 0;
        tmp.seekSet(0);
        tmp.read(&gzipmagic, 2);
        if(gzipmagic == 0x8B1F) //File header starts with gzip magic number
          rootTrackIndicies.add(i);
      }
    }
  }
  tmp.close();
  Serial.print("size of root tracks: "); Serial.println(rootTrackIndicies.size());
}

int RNG(int lower, int upper)
{
  return (trngGetRandomNumber() % (upper - lower)) + lower;
}

File getFileFromVwdIndex(uint32_t index)
{
  SD.vwd()->rewind();
  File tmp;
  for(uint32_t i = 0; i<index+1; i++)
  {
    tmp.close();
    tmp.openNext(SD.vwd(), O_READ);
  }
  return tmp;
}
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
void loop()
{    
  switch(VGMEngine.play())
  {
    case VGMEngineState::IDLE:
    break;
    case VGMEngineState::END_OF_TRACK:
      if(playMode == IN_ORDER || playMode == SHUFFLE_ALL || playMode == SHUFFLE_DIR)
        startTrack(NEXT);
    break;
    case VGMEngineState::PLAYING:
    break;
    case  VGMEngineState::ERROR:
      alertErrorState();
    break;
  }

  if(Serial.available() > 0) 
    handleSerialIn();

  //Debounced buttons
  for(uint8_t i = 0; i<5; i++)
  {
    buttons[i].update();
  }

  if(buttons[0].fell()) //Next
  {
    if(menuState == IN_MENU)
      nav.doNav(navCmd(enterCmd));
    else if(menuState == IN_VGM)
    {
      if(playMode == IN_ORDER || playMode == SHUFFLE_ALL || playMode == SHUFFLE_DIR)
        startTrack(NEXT);
    }
  }
  if(buttons[1].fell()) //Prev
  {
    if(menuState == IN_MENU)
        nav.doNav(navCmd(escCmd));
    else if(menuState == IN_VGM)
    {
      if(playMode == IN_ORDER || playMode == SHUFFLE_ALL || playMode == SHUFFLE_DIR)
        startTrack(PREV);
    }
  }
  if(buttons[2].fell()) //Up
  {
    if(menuState == IN_MENU)
      nav.doNav(navCmd(downCmd));
  }
  if(buttons[3].fell()) //Select
    {
      if(menuState == IN_MENU) //If you're in the file-picker, the select button is used to enter dirs
        nav.doNav(navCmd(enterCmd)); 
      else if(menuState == IN_VGM) //Otherwise, you can use the select key to go back to the file picker where you left off
      {
        menuState = IN_MENU;
        nav.timeOut=MENU_TIMEOUT_IN_SECONDS;
        nav.idleOff();
        nav.refresh();
      }
    }
  if(buttons[4].fell())//Down
  {
    if(menuState == IN_MENU)
      nav.doNav(navCmd(upCmd));
  }

  //UI
  if (nav.changed(0) && menuState == IN_MENU) 
  {//only draw if menu changed for gfx device
    //change checking leaves more time for other tasks
    u8g2.firstPage();
    do nav.doOutput(); while(u8g2.nextPage());
  }
}




//UI

//implementing the handler here after filePick is defined...
result filePick(eventMask event, navNode& _nav, prompt &item) 
{
  // switch(event) {//for now events are filtered only for enter, so we dont need this checking
  //   case enterCmd:
      if (_nav.root->navFocus==(navTarget*)&filePickMenu) {
        Serial.println();
        Serial.print("selected file:");
        Serial.println(filePickMenu.selectedFile);
        Serial.print("from folder:");
        Serial.println(filePickMenu.selectedFolder);
        if(filePickMenu.selectedFile.startsWith(".")) //Do not allow users to select meta files
          return proceed;
        menuState = IN_VGM;
        if(filePickMenu.selectedFolder != currentDir)
        {
          currentDir = filePickMenu.selectedFolder;
          if(playMode == SHUFFLE_DIR || playMode == SHUFFLE_ALL)
            clearRandomHistory();
        }
        getDirIndices(filePickMenu.selectedFolder, filePickMenu.selectedFile);
        if(playMode == SHUFFLE_DIR || playMode == SHUFFLE_ALL)
        {
          if(randFileList.size() == 0)
            randIndex = 0;
          else
            randIndex++;
          randFileList.add(dirCurIndex);
          randDirList.add(filePickMenu.selectedFolder);
        }
        startTrack(REQUEST, filePickMenu.selectedFolder+filePickMenu.selectedFile);
      }
  return proceed;
}

result onMenuIdle(menuOut& o,idleEvent e) 
{
  if (VGMEngine.state == PLAYING) 
  {
    switch(e)
    {
      case idleStart:
        
      break;
      case idling:
      {
        menuState = IN_VGM;
        drawOLEDTrackInfo();  
        nav.timeOut=0xFFFFFFFF;
        nav.refresh();
      }
      break;
      case idleEnd:
      nav.timeOut=MENU_TIMEOUT_IN_SECONDS;
      break;
    }
  }
  return proceed;
}

result onChoosePlaymode(eventMask e,navNode& _nav,prompt& item)
{
  if(e == exitEvent)
  {
    switch(playMode)
    {
      case PlayMode::LOOP:
      VGMEngine.maxLoops = 0xFFFF;
      mainMenu[2].disable();
      break;
      case PlayMode::SHUFFLE_ALL:
      VGMEngine.maxLoops = 3;
      mainMenu[2].enable();
      menuState = IN_VGM;
      nav.timeOut=0xFFFFFFFF;
      clearRandomHistory();
      startTrack(NEXT);
      drawOLEDTrackInfo();
      break;
      case PlayMode::IN_ORDER:
      VGMEngine.maxLoops = 3;
      mainMenu[2].enable();
      break;
      case PlayMode::SHUFFLE_DIR:
      VGMEngine.maxLoops = 3;
      mainMenu[2].enable();
      clearRandomHistory();
      break;
      case PlayMode::PAUSE:
      break;
      default:
      break;
    }
  }
  return proceed;
}

  //Handy old code

  //Direct IO examples for reading pins
  //if (REG_PORT_IN0 & PORT_PA19)  // if (digitalRead(12) == HIGH)
  //if (!(REG_PORT_IN0 | ~PORT_PA19)) // if (digitalRead(12) == LOW) FOR NON-PULLED PINS!
  //if(!(REG_PORT_IN1 & next_btn)) //LOW for PULLED PINS

  // //Group 1 is port B, PINCFG just wants the literal pin number on the port, DIRCLR and OUTSET want the masked PORT_XX00 *not* the PIN_XX00
  // //Prev button input pullup
  // PORT->Group[1].PINCFG[0].reg=(uint8_t)(PORT_PINCFG_INEN|PORT_PINCFG_PULLEN);
  // PORT->Group[1].DIRCLR.reg = PORT_PB00;
  // PORT->Group[1].OUTSET.reg = PORT_PB00;

  // //Rand button input pullup
  // PORT->Group[1].PINCFG[1].reg=(uint8_t)(PORT_PINCFG_INEN|PORT_PINCFG_PULLEN);
  // PORT->Group[1].DIRCLR.reg = PORT_PB01;
  // PORT->Group[1].OUTSET.reg = PORT_PB01;

  // //Next button input pullup
  // PORT->Group[1].PINCFG[4].reg=(uint8_t)(PORT_PINCFG_INEN|PORT_PINCFG_PULLEN);
  // PORT->Group[1].DIRCLR.reg = PORT_PB04;
  // PORT->Group[1].OUTSET.reg = PORT_PB04;

  // //Option button input pullup
  // PORT->Group[1].PINCFG[5].reg=(uint8_t)(PORT_PINCFG_INEN|PORT_PINCFG_PULLEN); 
  // PORT->Group[1].DIRCLR.reg = PORT_PB05;
  // PORT->Group[1].OUTSET.reg = PORT_PB05;

  // //Select button input pullup
  // PORT->Group[1].PINCFG[9].reg=(uint8_t)(PORT_PINCFG_INEN|PORT_PINCFG_PULLEN); 
  // PORT->Group[1].DIRCLR.reg = PORT_PB09;
  // PORT->Group[1].OUTSET.reg = PORT_PB09;

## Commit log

2020-12-23 Board v1 complete
    [MegaBlaster2-B_Cu.gbr, MegaBlaster2-B_Mask.gbr, MegaBlaster2-B_Paste.gbr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]
2021-01-07 Porting player
    [MegaBlaster2-B_Cu.gbr, MegaBlaster2-B_Mask.gbr, MegaBlaster2-B_Paste.gbr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]
2021-01-07 Programmed buttons
2021-01-07 Menu lib, neopixel removed from pcb, bootloader
    [MegaBlaster2-B_Cu.gbr, MegaBlaster2-B_Mask.gbr, MegaBlaster2-B_Paste.gbr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]
2021-01-07 silkscreen update
    [MegaBlaster2-B_Cu.gbr, MegaBlaster2-B_Mask.gbr, MegaBlaster2-B_Paste.gbr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]
2021-01-08 New ARM-optimized bus write algo
2021-01-11 custom board config
2021-01-11 Debounced buttons
2021-01-12 Fix U8G2 and index root
    [main.cpp]
2021-01-13 NEXT button IN_ORDER
2021-01-17 dir index from full path and root shuffle bugs fixed
    [main.cpp]
2021-01-18 PCB Update
    [MegaBlaster2-B_Cu.gbr, MegaBlaster2-B_Mask.gbr, MegaBlaster2-B_Paste.gbr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]
2021-01-20 DAC Stream early prototype
2021-01-25 paged RAM stores
    [MegaBlaster2_Baseplate_V2.3mf]
2021-01-31 Increase gzip buf and fix root file picking
    [main.cpp]
2021-02-11 New logo
    [MegaBlaster2_Baseplate_V3.3mf]
2021-02-21 Revise Instruction Manual
    * Fixed some minor grammar
    * Improved readability slightly (see comparison doc attached in comments)
    * Added PDF bookmarks by Word Headers option
    * Added hyperlink to www.aidanlawrence.com in first page
    * fixed some spelling, punctuation, and capitalization of software and hardware names
    * added mild disclaimer about ground loop isolators (they very often have low-pass filters and can affect audio quality, especially ones made for car stereo systems)
2021-02-23 Schematic cleanup
    [6x_OLED_Spacer_1.3mf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]
2021-03-12 Fixed in-order seek on root and remove meta files upon entering dir
    [main.cpp]
2021-03-13 SdFat patch to prevent sequetial, matching subsstring dirs from conflicting
    [main.cpp]
2021-04-16 Fixed shuffle bug and file order bug
    [main.cpp]
2021-10-08 Fixed call to true-rng for shuffled playlists
    [main.cpp]
2021-10-11 Fixed issue with DAC streams
    [main.cpp]
2022-02-01 YM channel muting fixed
    [main.cpp]
2026-08-23 Fix for delay timing and dac stream overflow
    [main.cpp]

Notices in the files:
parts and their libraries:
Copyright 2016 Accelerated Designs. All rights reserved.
